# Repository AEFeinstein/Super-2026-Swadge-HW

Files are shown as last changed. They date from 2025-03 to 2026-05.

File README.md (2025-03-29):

# Super Magfest 2026 Swadge Hardware

## Welcome

This is the hardware repository for the Super Magfest 2026 Swadge.

The corresponding firmware repository for the Super Magfest 2026 Swadge [can be found here](https://github.com/AEFeinstein/Super-2024-Swadge-FW).

If you have any questions, feel free to create a Github ticket or email us at circuitboards@magfest.org.

## Render

Coming eventually!

## Schematic

Coming eventually!

## Directories

### `art`

This directory has the SVGs used to generate the KiCad files. The SVGs are drawn in [Inkscape](https://inkscape.org/).

### `Swadge-Parts`

This directory is a git submodule which has all the parts, footprints, and 3D models used in the KiCad project.

### `Swadge-HW`

This directory has the KiCad project for the main Swadge PCB.

### `Swadge-HW/3d Print`

This directory has the 3D print files for the 2026 Swadge.

### `Swadge-HW/Manufacturing Information`

This directory has information about manufacturing the Swdage PCB.

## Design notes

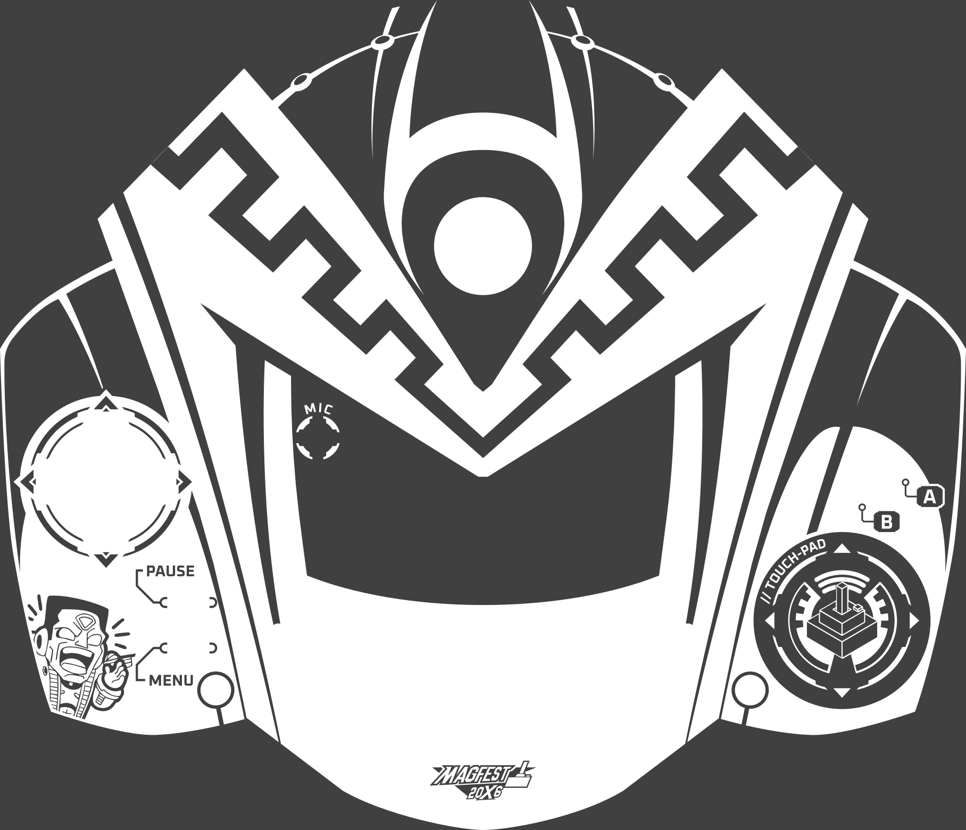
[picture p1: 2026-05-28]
art/SwadgeDesign-13-Export-01.png

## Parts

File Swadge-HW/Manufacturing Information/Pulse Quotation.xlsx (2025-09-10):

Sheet: PCB Specification
Your PCB Specification |  | Your PCB Specification
PCB Quantity | 1800pcs | PCB Quantity | 700pcs
Layer | 2layer | Layer | 2layer
PCB Thickness | 1.6mm | PCB Thickness | 1.6mm
Dimensions | 153*132mm | Dimensions | 153*132mm
Castellated Hole | No | Castellated Hole | No
PCB Color | Black | PCB Color | Blue
Surface Finish | HASL Lead Free | Surface Finish | HASL Lead Free
Copper Weight | 1oz | Copper Weight | 1oz
Text Color | White | Text Color | White
Different Design | 1 | Different Design | 1
Please find more PCB information on our on-line PCB ordering Page
https://www.elecrow.com/pcb-manufacturing.html

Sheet: BOM - BLUE
Swadge 2026 - BLUE
# | Reference | Qty | Value | Package | Manufacturer Part number | Description | SMD | THT | Original | Elecrow PN | Note
1 | R6,R18,R27,R28,R35 | 5 | 5.1kÎ© | R_0603_1608Metric | C23186 | Resistor US symbol |  |  | Y | C23186
2 | C1,C4,C5,C6,C7,C11,C15,C17,C19 | 9 | 1Î¼F | C_0603_1608Metric | C15849 | Unpolarized capacitor |  |  | Y | C15849
3 | U2 | 1 | RB017A1505A | NULL | ~ | 240x280 color TFT with rounded corners |  |  | N | ~ | Display
4 | U1 | 1 | ESP32-S2-MINI-2 | ESP32-S2-MINI-2 | C3013908 |  |  |  |  | C3013908 | Use module w. 4MB Flash, 2MB PSRAM (N4R2)
5 | U6 | 1 | LSM6DSL | LGA-14_3x2.5mm_P0.5mm_LayoutBorder3x4y | C967633 |  |  |  |  | C967633
6 | RV1 | 1 | R_Potentiometer_US_SMD | RK10J11R001Y | C3020613 | ±30% 10k? SMD-5P,14x2.5mm Potentiometers, Variable Resistors ROHS |  |  |  | C3020613
7 | U9 | 1 | INGHAi_GSPK2307P-8R1W | INGHAi GSPK2308P-8R0.5W | C530531 |  |  |  | Y | C530531
8 | MK1 | 1 | Microphone | INGHAi_MIC_GMI4013S-2C58DB | C529869 | Microphone |  |  | N | C529869
9 | BT1,BT2,BT3 | 3 | Battery | 2460 | ~ | BATT HOLDER AA 1 CELL PC PIN |  |  | Y | ~ | Use through-hole AA Battery Holder in Style of Keystone 2460. Two fins hold batteries, not four fins.
10 | U5 | 1 | RB017A1505A_Connector | HCTL HC-FPC-03-10-15RLTAG-TUCKED | C3012328 |  |  |  | Y | C3012328
11 | L1 | 1 | 33uH_500mA | L_1210_3225Metric | C90317 | Inductor |  |  | Y | C90317
12 | D11 | 1 | SP0503BAHT | SOT-143 | C2682275 | TVS Diode Array, 5.5V Standoff, 3 Channels, SOT-143 package |  |  | Y | C2682275
13 | J1 | 1 | Conn_02x03_Odd_Even | PinHeader_2x03_P2.54mm_Vertical | C92272 | Generic connector, double row, 02x03 |  |  | Y | C92272
14 | SW7,SW8 | 2 | B3FS-4002P | B3FS4002P | C5377634 | Black Cap Tactile Switch, SPST-NO 50 mA @ 24 V dc 0.4mm |  |  | Y | C5377634 | Use standard 12mmx12mm SMT box tactile buttons with flat top. Similar to TL3300DF160Q.
15 | D1,D2,D3,D4,D5,D6 | 6 | SK6812-SIDE-A | SK6812_SIDE_2 | C2890037 |  |  |  | Y | C2890037
16 | P1 | 1 | USB_C_Plug_USB2.0 | USB_C_Receptacle_HRO_TYPE-C-31-M-12 | C2765186 | USB 2.0-only Type-C Plug connector |  |  | Y | C2765186 | https://www.usb.org/sites/default/files/documents/usb_type-c.zip
17 | L3 | 1 | 2.2uH | L_1008_2520Metric | C216158 | Inductor |  |  | Y | C216158
18 | J2 | 1 | PJ-307C | PJ-307C | C16684 |  |  |  | N | C16684
19 | U8 | 1 | FM8002A | SOP-8_3.9x4.9mm_P1.27mm | C94625 | Mono Audio Amplifier |  |  | N | C94625
20 | D10,D12 | 2 | D | D_SMA | C22452 | Diode |  |  | Y | C22452
21 | U3 | 1 | M3410 | SOT-23-5 | C42420805 | M3410LB-N |  |  | Y | C42420805 | May be FP6396, M3406, LP3220S, etc...
22 | Q1 | 1 | Q_PMOS_GSD | SOT-23 | C2763847 | P-MOSFET transistor, gate/source/drain |  |  | Y | C2763847
23 | SW1,SW2,SW3,SW4,SW5,SW6 | 6 | YTS-D003-1A | YTS-D003-1A | C2910918 |  |  |  | Y | C2910918 | Use low operating force (100gf) SMT box tactile buttons
24 | U7 | 1 | GENERIC_LDO_GOI | SOT-23 | C347374 |  |  |  | Y | C347374
25 | SW9 | 1 | SW_SPDT_1825232-1 | 1825232-1 | C393937 | Slide Switch SPDT Through Hole, Right Angle |  |  | Y | C393937 | Use SPDT slide switch. Similar to 1825232-1
26 | C2,C12,C20,C22 | 4 | 22uF | C_0603_1608Metric | C159801 | Unpolarized capacitor |  |  | Y | C159801
27 | C18 | 1 | 0.39uF | C_0603_1608Metric | C376833 | Unpolarized capacitor |  |  | Y | C376833
28 | C14 | 1 | 1uF | C_0603_1608Metric | C15849 | Unpolarized capacitor |  |  | Y | C15849
29 | C9 | 1 | 4.7nF | C_0603_1608Metric | C53987 | Unpolarized capacitor |  |  | Y | C53987
30 | C21 | 1 | 2.2uF | C_0603_1608Metric | C6119848 | Unpolarized capacitor |  |  | Y | C6119848
31 | C3,C10,C13,C16,C23,C25 | 6 | 0.1uF | C_0603_1608Metric | C282519 | Unpolarized capacitor |  |  | Y | C282519
32 | R21,R25 | 2 | 43k | R_0603_1608Metric | C23172 | Resistor US symbol |  |  | Y | C23172
33 | R3 | 1 | 12k | R_0603_1608Metric | C22790 | Resistor US symbol |  |  | Y | C22790
34 | R2,R4,R8,R13,R14 | 5 | 33k | R_0603_1608Metric | C23140 | Resistor US symbol |  |  | Y | C23140
35 | R20,R23,R29,R30,R31,R32,R33,R34 | 8 | 22 | R_0603_1608Metric | C25092 | Resistor US symbol |  |  | Y | C25092 | BLUE SOLDERMASK VARIANT
36 | R19 | 1 | 120 | R_0603_1608Metric | C313655 | Resistor US symbol |  |  | Y | C313655
37 | R10,R11,R12,R15,R16,R17 | 6 | 50 | R_0603_1608Metric | C2907048 | Resistor US symbol |  |  | Y | C2907048
38 | R5,R9 | 2 | 20k | R_0603_1608Metric | C2907011 | Resistor US symbol |  |  | Y | C2907011
39 | R1,R7,R22,R24,R26 | 5 | 10k | R_0603_1608Metric | C25804 | Resistor US symbol |  |  | Y | C25804
40 | U11 | 1 | CH32V003F4U6 | QFN-20-1EP_3x3mm_P0.4mm_EP1.65x1.65mm | C5299908 |  |  |  | N | C5299908
42 | D13,D14,D15,D16,D17,D18,D19,D20,D21,D22,D23,D24,D25,D26,D27,D28,D29,D30,D31,D32,D33,D34,D35,D36,D37,D38,D39,D40,D41,D42,D43,D44,D45,D46,D47,D48,D49,D50,D51,D52,D53,D54,D55,D56,D57,D58,D59,D60,D61,D62,D63,D64,D65,D66,D67,D68,D69,D70,D71,D72,D73,D74,D75,D76,D77,D78,D79,D80,D81,D82,D83,D84 | 72 | A-SP192GB1D-A02-4T | LED 0603 | C5355458 | 20mA 1420mcd Diode Ice Blue |  |  | N | C5355458 | BLUE SOLDERMASK VARIANT

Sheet: BOM - BLACK
Swadge 2026 - BLUE
# | Reference | Qty | Value | Package | Manufacturer Part number | Description | SMD | THT | Original | Elecrow PN | Note
1 | R6,R18,R27,R28,R35 | 5 | 5.1kÎ© | R_0603_1608Metric | C23186 | Resistor US symbol |  |  | Y | C23186
2 | C1,C4,C5,C6,C7,C11,C15,C17,C19 | 9 | 1Î¼F | C_0603_1608Metric | C15849 | Unpolarized capacitor |  |  | Y | C15849
3 | U2 | 1 | RB017A1505A | NULL | ~ | 240x280 color TFT with rounded corners |  |  | N | ~ | Display
4 | U1 | 1 | ESP32-S2-MINI-2 | ESP32-S2-MINI-2 | C3013908 |  |  |  |  | C3013908 | Use module w. 4MB Flash, 2MB PSRAM (N4R2)
5 | U6 | 1 | LSM6DSL | LGA-14_3x2.5mm_P0.5mm_LayoutBorder3x4y | C967633 |  |  |  |  | C967633
6 | RV1 | 1 | R_Potentiometer_US_SMD | RK10J11R001Y | C3020613 | ±30% 10k? SMD-5P,14x2.5mm Potentiometers, Variable Resistors ROHS |  |  |  | C3020613
7 | U9 | 1 | INGHAi_GSPK2307P-8R1W | INGHAi GSPK2308P-8R0.5W | C530531 |  |  |  | Y | C530531
8 | MK1 | 1 | Microphone | INGHAi_MIC_GMI4013S-2C58DB | C529869 | Microphone |  |  | N | C529869
9 | BT1,BT2,BT3 | 3 | Battery | 2460 | ~ | BATT HOLDER AA 1 CELL PC PIN |  |  | Y | ~ | Use through-hole AA Battery Holder in Style of Keystone 2460. Two fins hold batteries, not four fins.
10 | U5 | 1 | RB017A1505A_Connector | HCTL HC-FPC-03-10-15RLTAG-TUCKED | C3012328 |  |  |  | Y | C3012328
11 | L1 | 1 | 33uH_500mA | L_1210_3225Metric | C90317 | Inductor |  |  | Y | C90317
12 | D11 | 1 | SP0503BAHT | SOT-143 | C2682275 | TVS Diode Array, 5.5V Standoff, 3 Channels, SOT-143 package |  |  | Y | C2682275
13 | J1 | 1 | Conn_02x03_Odd_Even | PinHeader_2x03_P2.54mm_Vertical | C92272 | Generic connector, double row, 02x03 |  |  | Y | C92272
14 | SW7,SW8 | 2 | B3FS-4002P | B3FS4002P | C5377634 | Black Cap Tactile Switch, SPST-NO 50 mA @ 24 V dc 0.4mm |  |  | Y | C5377634 | Use standard 12mmx12mm SMT box tactile buttons with flat top. Similar to TL3300DF160Q.
15 | D1,D2,D3,D4,D5,D6 | 6 | SK6812-SIDE-A | SK6812_SIDE_2 | C2890037 |  |  |  | Y | C2890037
16 | P1 | 1 | USB_C_Plug_USB2.0 | USB_C_Receptacle_HRO_TYPE-C-31-M-12 | C2765186 | USB 2.0-only Type-C Plug connector |  |  | Y | C2765186 | https://www.usb.org/sites/default/files/documents/usb_type-c.zip
17 | L3 | 1 | 2.2uH | L_1008_2520Metric | C216158 | Inductor |  |  | Y | C216158
18 | J2 | 1 | PJ-307C | PJ-307C | C16684 |  |  |  | N | C16684
19 | U8 | 1 | FM8002A | SOP-8_3.9x4.9mm_P1.27mm | C94625 | Mono Audio Amplifier |  |  | N | C94625
20 | D10,D12 | 2 | D | D_SMA | C22452 | Diode |  |  | Y | C22452
21 | U3 | 1 | M3410 | SOT-23-5 | C42420805 | M3410LB-N |  |  | Y | C42420805 | May be FP6396, M3406, LP3220S, etc...
22 | Q1 | 1 | Q_PMOS_GSD | SOT-23 | C2763847 | P-MOSFET transistor, gate/source/drain |  |  | Y | C2763847
23 | SW1,SW2,SW3,SW4,SW5,SW6 | 6 | YTS-D003-1A | YTS-D003-1A | C2910918 |  |  |  | Y | C2910918 | Use low operating force (100gf) SMT box tactile buttons
24 | U7 | 1 | GENERIC_LDO_GOI | SOT-23 | C347374 |  |  |  | Y | C347374
25 | SW9 | 1 | SW_SPDT_1825232-1 | 1825232-1 | C393937 | Slide Switch SPDT Through Hole, Right Angle |  |  | Y | C393937 | Use SPDT slide switch. Similar to 1825232-1
26 | C2,C12,C20,C22 | 4 | 22uF | C_0603_1608Metric | C159801 | Unpolarized capacitor |  |  | Y | C159801
27 | C18 | 1 | 0.39uF | C_0603_1608Metric | C376833 | Unpolarized capacitor |  |  | Y | C376833
28 | C14 | 1 | 1uF | C_0603_1608Metric | C15849 | Unpolarized capacitor |  |  | Y | C15849
29 | C9 | 1 | 4.7nF | C_0603_1608Metric | C53987 | Unpolarized capacitor |  |  | Y | C53987
30 | C21 | 1 | 2.2uF | C_0603_1608Metric | C6119848 | Unpolarized capacitor |  |  | Y | C6119848
31 | C3,C10,C13,C16,C23,C25 | 6 | 0.1uF | C_0603_1608Metric | C282519 | Unpolarized capacitor |  |  | Y | C282519
32 | R21,R25 | 2 | 43k | R_0603_1608Metric | C23172 | Resistor US symbol |  |  | Y | C23172
33 | R3 | 1 | 12k | R_0603_1608Metric | C22790 | Resistor US symbol |  |  | Y | C22790
34 | R2,R4,R8,R13,R14 | 5 | 33k | R_0603_1608Metric | C23140 | Resistor US symbol |  |  | Y | C23140
35 | R20,R23,R29,R30,R31,R32,R33,R34 | 8 | 47 | R_0603_1608Metric | C2907174 | Resistor US symbol |  |  | Y | C2907174 | BLACK SOLDERMASK VARIANT
36 | R19 | 1 | 120 | R_0603_1608Metric | C313655 | Resistor US symbol |  |  | Y | C313655
37 | R10,R11,R12,R15,R16,R17 | 6 | 50 | R_0603_1608Metric | C2907048 | Resistor US symbol |  |  | Y | C2907048
38 | R5,R9 | 2 | 20k | R_0603_1608Metric | C2907011 | Resistor US symbol |  |  | Y | C2907011
39 | R1,R7,R22,R24,R26 | 5 | 10k | R_0603_1608Metric | C25804 | Resistor US symbol |  |  | Y | C25804
40 | U11 | 1 | CH32V003F4U6 | QFN-20-1EP_3x3mm_P0.4mm_EP1.65x1.65mm | C5299908 |  |  |  | N | C5299908
42 | D13,D14,D15,D16,D17,D18,D19,D20,D21,D22,D23,D24,D25,D26,D27,D28,D29,D30,D31,D32,D33,D34,D35,D36,D37,D38,D39,D40,D41,D42,D43,D44,D45,D46,D47,D48,D49,D50,D51,D52,D53,D54,D55,D56,D57,D58,D59,D60,D61,D62,D63,D64,D65,D66,D67,D68,D69,D70,D71,D72,D73,D74,D75,D76,D77,D78,D79,D80,D81,D82,D83,D84 | 72 | XL-1608SURC-06FJ | LED 0603 | C7371900 | 20mA Water Clear 600mcd op View Mount 618nm~630nm Red |  |  | N | C7371900 | BLACK SOLDERMASK VARIANT

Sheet: Position File
designator | footprint | pos_x | pos_y | Layer | rotation
BT1 | 2460 | 118.6449 | -96.1958 | bottom | 90.00
BT2 | 2460 | 151.1449 | -49.7873 | bottom | 0
BT3 | 2460 | 183.6449 | -96.1958 | bottom | -90
C1 | C_0603_1608Metric | 193.7017 | -45.7603 | bottom | 45
C2 | C_0603_1608Metric | 203.8166 | -70.9114 | bottom | -135
C3 | C_0603_1608Metric | 201.7659 | -68.8608 | bottom | -135
C6 | C_0603_1608Metric | 203.4592 | -86.415 | bottom | 90
C7 | C_0603_1608Metric | 209.5592 | -90.285 | bottom | 0
C9 | C_0603_1608Metric | 138.0199 | -92.3922 | bottom | 180
C10 | C_0603_1608Metric | 164.0417 | -87.34 | bottom | 180
C11 | C_0603_1608Metric | 156.2725 | -131.82 | bottom | 180
C12 | C_0603_1608Metric | 160.9917 | -87.315 | bottom | 0
C13 | C_0603_1608Metric | 159.2042 | -85.74 | bottom | 180
C14 | C_0603_1608Metric | 140.3917 | -72.1525 | bottom | -90
C15 | C_0603_1608Metric | 131.2417 | -73.215 | bottom | 90
C16 | C_0603_1608Metric | 163.4751 | -125.8042 | bottom | -90
C18 | C_0603_1608Metric | 136.5349 | -65.3815 | bottom | 90
C19 | C_0603_1608Metric | 158.3749 | -124.6865 | bottom | -90
C20 | C_0603_1608Metric | 135.8199 | -88.5547 | bottom | 90
C21 | C_0603_1608Metric | 157.6574 | -82.69 | bottom | 180
C22 | C_0603_1608Metric | 150.9749 | -126.499 | bottom | 0
C23 | C_0603_1608Metric | 156.7749 | -124.6865 | bottom | -90
C25 | C_0603_1608Metric | 155.1749 | -124.6865 | bottom | -90
D10 | D_SMA | 152.4749 | -130.899 | bottom | -90
D11 | SOT-143 | 206.6671 | -80.9211 | bottom | 45
D12 | D_SMA | 209.0049 | -72.6811 | bottom | -120
J2 | PJ-307C | 125.566 | -31.2422 | bottom | -155
L1 | L_1210_3225Metric | 148.9949 | -129.659 | bottom | 90
L3 | L_1008_2520Metric | 206.2199 | -85.759 | bottom | 0
P1 | USB_C_Receptacle_HRO_TYPE-C-31-M-12 | 222.4127 | -75.1863 | bottom | -45
Q1 | SOT-23 | 156.0749 | -129.149 | bottom | 180
R1 | R_0603_1608Metric | 191.5362 | -47.9259 | bottom | 45
R2 | R_0603_1608Metric | 138.8449 | -88.5172 | bottom | 90
R3 | R_0603_1608Metric | 138.0324 | -90.8172 | bottom | 180
R5 | R_0603_1608Metric | 137.9042 | -69.765 | bottom | 0
R6 | R_0603_1608Metric | 187.788 | -51.574 | bottom | 45
R7 | R_0603_1608Metric | 158.67 | -129.1675 | bottom | 90
R8 | R_0603_1608Metric | 159.9667 | -83.44 | bottom | 90
R9 | R_0603_1608Metric | 134.1324 | -66.1172 | bottom | 180
R10 | R_0603_1608Metric | 215.0274 | -104.959 | bottom | 0
R11 | R_0603_1608Metric | 205.6649 | -104.989 | bottom | 180
R12 | R_0603_1608Metric | 194.1449 | -124.8172 | bottom | 0
R13 | R_0603_1608Metric | 204.9598 | -77.3582 | bottom | -45
R14 | R_0603_1608Metric | 203.1598 | -79.2582 | bottom | -45
R15 | R_0603_1608Metric | 205.2449 | -123.0295 | bottom | -90
R16 | R_0603_1608Metric | 194.6049 | -120.559 | bottom | -90
R17 | R_0603_1608Metric | 208.0449 | -118.7172 | bottom | -90
R18 | R_0603_1608Metric | 166.2542 | -82.44 | bottom | 180
R19 | R_0603_1608Metric | 141.9917 | -72.1525 | bottom | -90
R20 | R_0603_1608Metric | 154.7649 | -96.7515 | bottom | -90
R21 | R_0603_1608Metric | 209.5592 | -88.715 | bottom | 180
R22 | R_0603_1608Metric | 210.3092 | -86.3275 | bottom | 90
R23 | R_0603_1608Metric | 148.4449 | -100.9297 | bottom | -90
R24 | R_0603_1608Metric | 205.8592 | -91.915 | bottom | 180
R25 | R_0603_1608Metric | 203.5592 | -89.515 | bottom | 90
R26 | R_0603_1608Metric | 150.9749 | -124.899 | bottom | 0
R29 | R_0603_1608Metric | 155.9049 | -101.049 | bottom | 180
R31 | R_0603_1608Metric | 146.8649 | -112.1585 | bottom | -90
R33 | R_0603_1608Metric | 150.7549 | -112.499 | bottom | -90
R34 | R_0603_1608Metric | 156.5949 | -112.139 | bottom | -90
R35 | R_0603_1608Metric | 152.8874 | -91.419 | bottom | 0
RV1 | RK10J11R001Y | 85.7449 | -73.4172 | bottom | -141
SW9 | 1825232-1 | 213.3291 | -68.0832 | bottom | -30
U1 | ESP32-S2-MINI-1 | 195.9449 | -59.1172 | bottom | 135
U3 | SOT-23-5 | 206.2092 | -89.115 | bottom | -90
U6 | LGA-14_3x2.5mm_P0.5mm_LayoutBorder3x4y | 162.5167 | -85.015 | bottom | 180
U7 | SOT-23 | 160.9749 | -124.449 | bottom | 0
U8 | SOP-8_3.9x4.9mm_P1.27mm | 135.6917 | -73.365 | bottom | 180
U10 | BGA-4-.83x.83 | 160.1917 | -81.24 | bottom | 0
C4 | C_0603_1608Metric | 175.5449 | -41.9172 | top | 50
C5 | C_0603_1608Metric | 172.1449 | -91.359 | top | 180
C17 | C_0603_1608Metric | 102.3945 | -106.5957 | top | -160
D1 | SK6812_SIDE_2 | 177.2553 | -44.6795 | top | 50
D2 | SK6812_SIDE_2 | 197.0221 | -105.1283 | top | -107
D3 | SK6812_SIDE_2 | 171.4191 | -87.3315 | top | -148
D4 | SK6812_SIDE_2 | 130.2124 | -86.912 | top | 148
D5 | SK6812_SIDE_2 | 105.2533 | -105.0087 | top | 107
D6 | SK6812_SIDE_2 | 125.1704 | -44.7883 | top | -50
D13 | LED_0603_1608Metric | 127.9449 | -95.3172 | top | 45
D14 | LED_0603_1608Metric | 127.9449 | -98.3172 | top | 45
D15 | LED_0603_1608Metric | 127.9449 | -101.3172 | top | 45
D16 | LED_0603_1608Metric | 127.9449 | -104.3172 | top | 45
D17 | LED_0603_1608Metric | 127.9449 | -107.3172 | top | 45
D18 | LED_0603_1608Metric | 127.9449 | -110.3172 | top | 45
D19 | LED_0603_1608Metric | 159.707 | -107.3287 | top | 45
D20 | LED_0603_1608Metric | 159.707 | -110.3287 | top | 45
D21 | LED_0603_1608Metric | 130.9449 | -95.3172 | top | 45
D22 | LED_0603_1608Metric | 130.9449 | -98.3172 | top | 45
D23 | LED_0603_1608Metric | 130.9449 | -101.3172 | top | 45
D24 | LED_0603_1608Metric | 130.9449 | -104.3172 | top | 45
D25 | LED_0603_1608Metric | 130.9449 | -107.3172 | top | 45
D26 | LED_0603_1608Metric | 130.9449 | -110.3172 | top | 45
D27 | LED_0603_1608Metric | 162.707 | -107.3287 | top | 45
D28 | LED_0603_1608Metric | 162.707 | -110.3287 | top | 45
D29 | LED_0603_1608Metric | 133.9449 | -95.3172 | top | 45
D30 | LED_0603_1608Metric | 133.9449 | -98.5172 | top | 45
D31 | LED_0603_1608Metric | 133.9449 | -101.3172 | top | 45
D32 | LED_0603_1608Metric | 133.9449 | -104.3172 | top | 45
D33 | LED_0603_1608Metric | 133.9449 | -107.3172 | top | 45
D34 | LED_0603_1608Metric | 133.9449 | -110.3172 | top | 45
D35 | LED_0603_1608Metric | 165.707 | -107.3287 | top | 45
D36 | LED_0603_1608Metric | 165.707 | -110.3287 | top | 45
D37 | LED_0603_1608Metric | 136.9449 | -95.3172 | top | 45
D38 | LED_0603_1608Metric | 136.9449 | -98.5172 | top | 45
D39 | LED_0603_1608Metric | 136.9449 | -101.3172 | top | 45
D40 | LED_0603_1608Metric | 136.9449 | -104.3172 | top | 45
D41 | LED_0603_1608Metric | 136.9449 | -107.3172 | top | 45
D42 | LED_0603_1608Metric | 136.9449 | -110.3172 | top | 45
D43 | LED_0603_1608Metric | 168.707 | -107.3287 | top | 45
D44 | LED_0603_1608Metric | 168.707 | -110.3287 | top | 45
D45 | LED_0603_1608Metric | 139.9449 | -95.3172 | top | 45
D46 | LED_0603_1608Metric | 139.9449 | -98.3172 | top | 45
D47 | LED_0603_1608Metric | 139.9449 | -101.3172 | top | 45
D48 | LED_0603_1608Metric | 139.9449 | -104.3172 | top | 45
D49 | LED_0603_1608Metric | 139.9449 | -107.3172 | top | 45
D50 | LED_0603_1608Metric | 139.9449 | -110.3172 | top | 45
D51 | LED_0603_1608Metric | 171.707 | -107.3287 | top | 45
D52 | LED_0603_1608Metric | 171.707 | -110.3287 | top | 45
D53 | LED_0603_1608Metric | 142.9449 | -95.3172 | top | 45
D54 | LED_0603_1608Metric | 142.9449 | -98.3172 | top | 45
D55 | LED_0603_1608Metric | 142.9449 | -101.3172 | top | 45
D56 | LED_0603_1608Metric | 142.9449 | -104.3172 | top | 45
D57 | LED_0603_1608Metric | 142.9449 | -107.3172 | top | 45
D58 | LED_0603_1608Metric | 142.9449 | -110.3172 | top | 45
D59 | LED_0603_1608Metric | 174.707 | -107.3287 | top | 45
D60 | LED_0603_1608Metric | 174.707 | -110.3287 | top | 45
D61 | LED_0603_1608Metric | 159.707 | -95.3287 | top | 45
D62 | LED_0603_1608Metric | 168.707 | -95.3287 | top | 45
D63 | LED_0603_1608Metric | 159.707 | -98.3287 | top | 45
D64 | LED_0603_1608Metric | 168.707 | -98.3287 | top | 45
D65 | LED_0603_1608Metric | 159.707 | -101.3287 | top | 45
D66 | LED_0603_1608Metric | 168.707 | -101.3287 | top | 45
D67 | LED_0603_1608Metric | 159.707 | -104.3287 | top | 45
D68 | LED_0603_1608Metric | 168.707 | -104.3287 | top | 45
D69 | LED_0603_1608Metric | 162.707 | -95.3287 | top | 45
D70 | LED_0603_1608Metric | 171.707 | -95.3287 | top | 45
D71 | LED_0603_1608Metric | 162.707 | -98.3287 | top | 45
D72 | LED_0603_1608Metric | 171.707 | -98.3287 | top | 45
D73 | LED_0603_1608Metric | 162.707 | -101.3287 | top | 45
D74 | LED_0603_1608Metric | 171.707 | -101.3287 | top | 45
D75 | LED_0603_1608Metric | 162.707 | -104.3287 | top | 45
D76 | LED_0603_1608Metric | 171.707 | -104.3287 | top | 45
D77 | LED_0603_1608Metric | 165.707 | -95.3287 | top | 45
D78 | LED_0603_1608Metric | 174.707 | -95.3287 | top | 45
D79 | LED_0603_1608Metric | 165.707 | -98.3287 | top | 45
D80 | LED_0603_1608Metric | 174.707 | -98.3287 | top | 45
D81 | LED_0603_1608Metric | 165.707 | -101.3287 | top | 45
D82 | LED_0603_1608Metric | 174.707 | -101.3287 | top | 45
D83 | LED_0603_1608Metric | 165.707 | -104.3287 | top | 45
D84 | LED_0603_1608Metric | 174.707 | -104.3287 | top | 45
J1 | PinSocket_2x03_P2.54mm_Vertical | 175.1449 | -30.7172 | top | 90
MK1 | INGHAi_MIC_GMI4013S-2C58DB | 124.9449 | -91.559 | top | 0
R4 | R_0603_1608Metric | 174.498 | -47.1922 | top | -40
R27 | R_0603_1608Metric | 209.5598 | -81.5718 | top | 45
R28 | R_0603_1608Metric | 212.2217 | -78.8722 | top | 45
R30 | R_0603_1608Metric | 148.9449 | -105.7297 | top | 90
R32 | R_0603_1608Metric | 148.9449 | -108.9297 | top | 90
SW1 | YTS-D003-1A | 91.3449 | -92.8172 | top | 45
SW2 | YTS-D003-1A | 97.0668 | -98.5391 | top | -45
SW3 | YTS-D003-1A | 85.5784 | -98.5836 | top | 135
SW4 | YTS-D003-1A | 91.3003 | -104.3056 | top | -135
SW5 | YTS-D003-1A | 104.25 | -124.995 | top | 180
SW6 | YTS-D003-1A | 104.25 | -117.875 | top | 180
SW7 | B3FS4002P | 208.0724 | -97.5204 | top | -60
SW8 | B3FS4002P | 219.504 | -90.9204 | top | -60
U2 | NULL | -28.508 | -117.0182 | top | 0
U5 | HCTL_HC-FPC-03-10-15RLTAG-TUCKED | 151.1449 | -128.8172 | top | 0
U9 | INGHAi_GSPK2308P-8R0.5W | 151.3449 | -61.0172 | top | 0
U11 | QFN-20-1EP_3x3mm_P0.4mm_EP1.65x1.65mm | 153.3049 | -107.7872 | top | 180

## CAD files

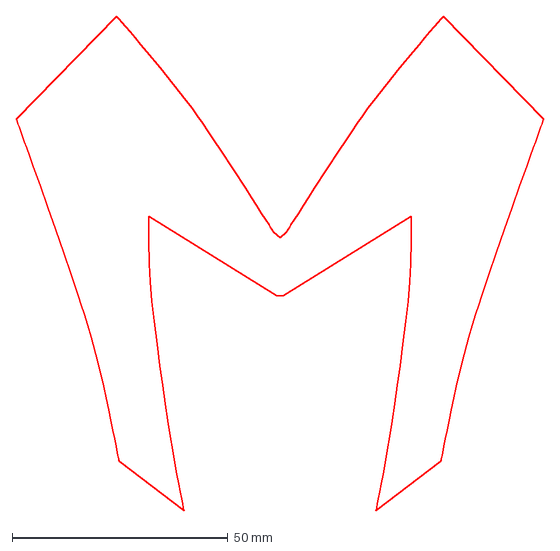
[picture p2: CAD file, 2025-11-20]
art/acylic_10102025.dxf
122.3 x 114.6 mm

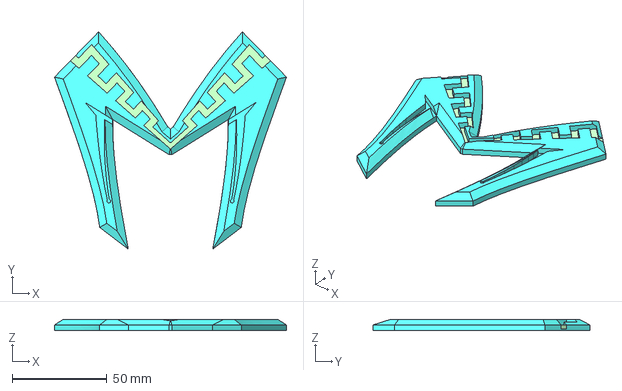
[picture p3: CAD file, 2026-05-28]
Swadge-HW/3D-Print/M-Diffuser.step
122.3 x 114.6 x 6.00 mm

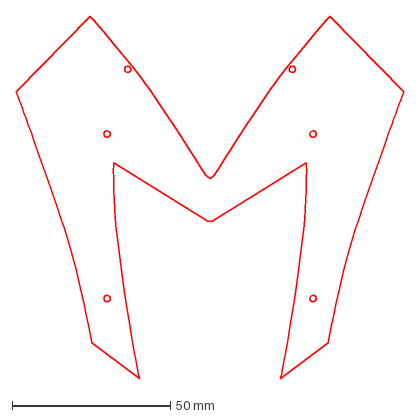
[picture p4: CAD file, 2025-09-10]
art/acrylic_992025.dxf
122.3 x 114.6 mm

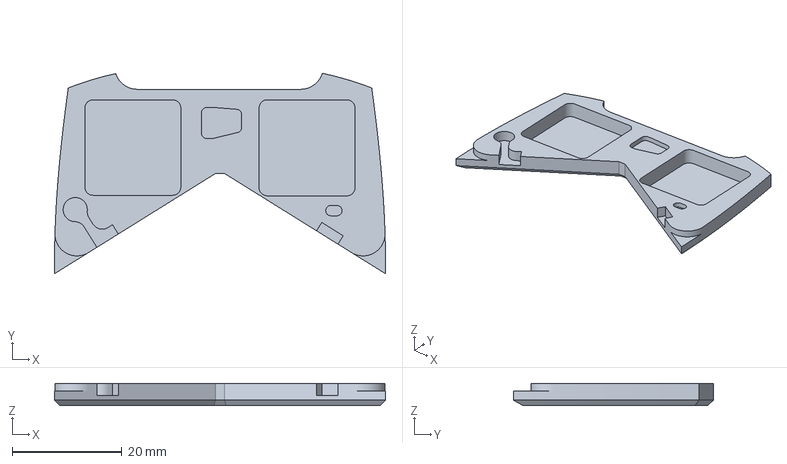
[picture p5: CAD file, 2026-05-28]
Swadge-HW/3D-Print/Open-Visor-orca.3mf
60.3 x 36.5 x 4.05 mm

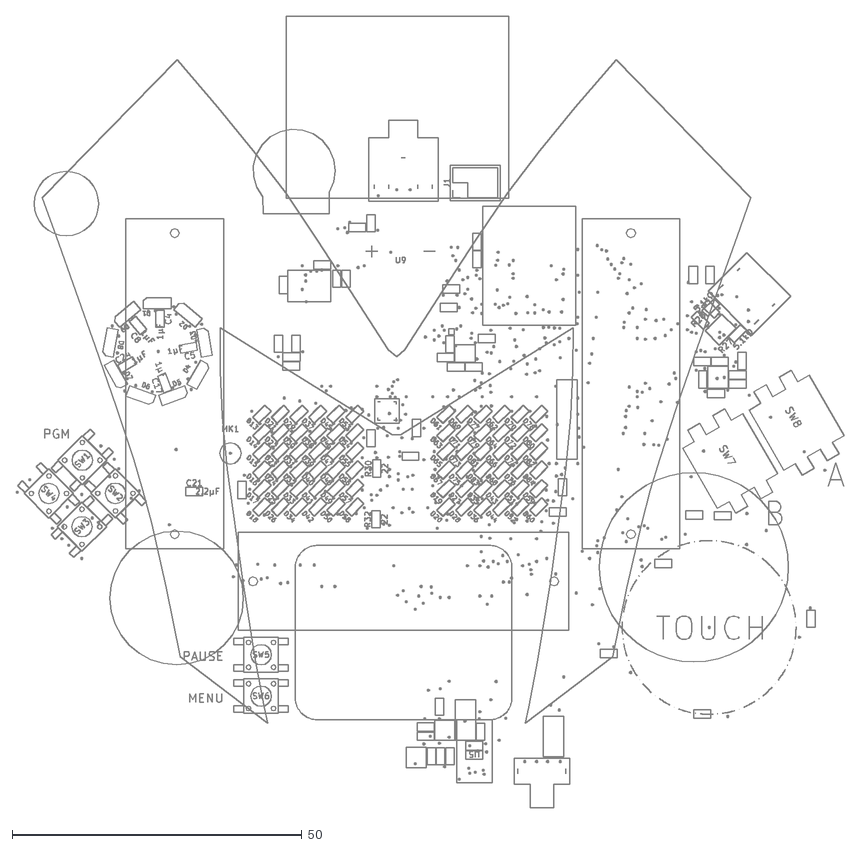
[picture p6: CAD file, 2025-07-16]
art/acrylic_7162025.dxf
142.9 x 136.6

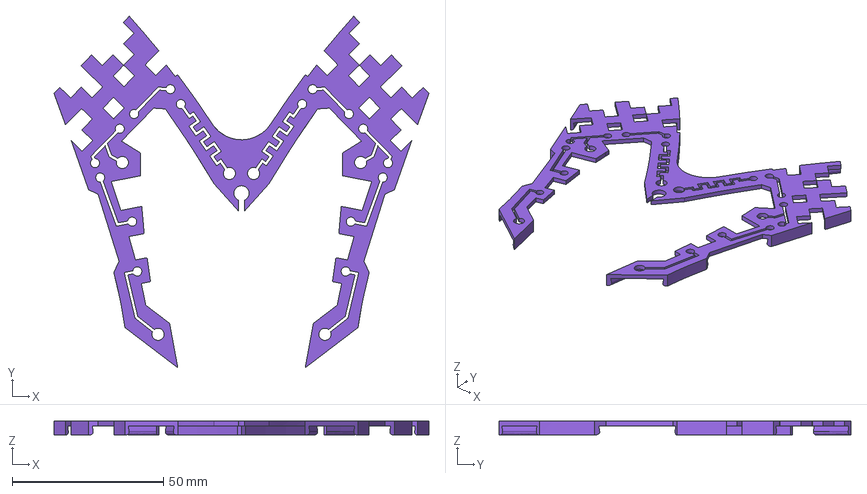
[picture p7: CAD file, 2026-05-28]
Swadge-HW/3D-Print/Corruption Crest.step
124.0 x 116.3 x 4.60 mm

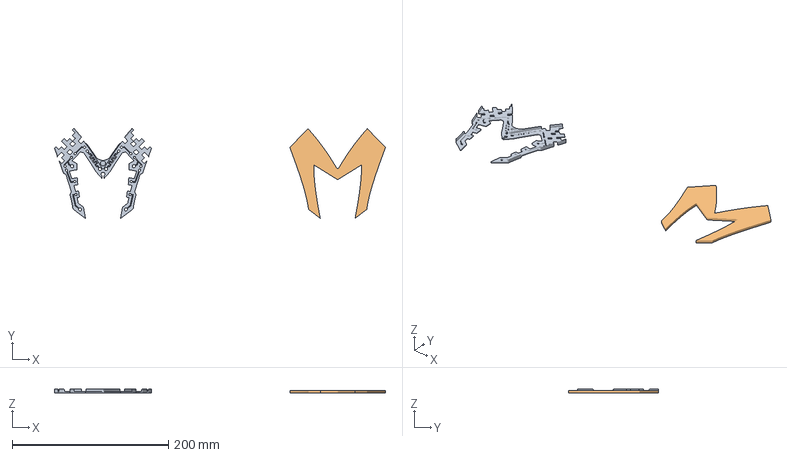
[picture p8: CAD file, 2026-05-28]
Swadge-HW/3D-Print/Corruption-Crest+Acrylic-Orca.3mf
423.2 x 115.4 x 4.60 mm
Corruption-Crest
Faux-Acrylic

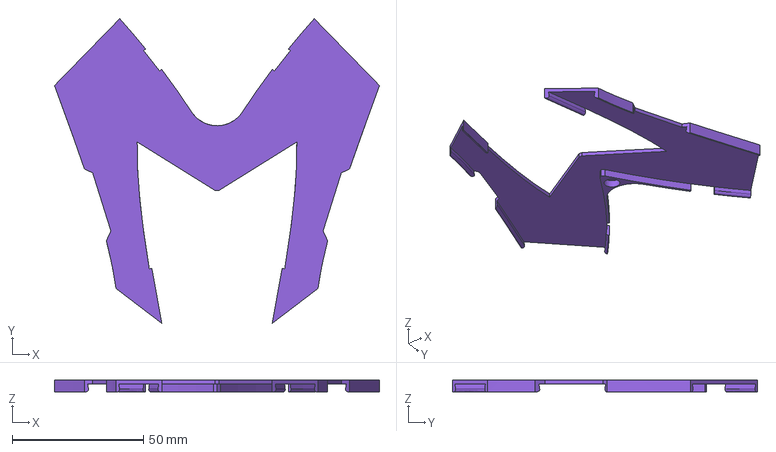
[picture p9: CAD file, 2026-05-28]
Swadge-HW/3D-Print/Crest-Diffuser-Template.step
124.0 x 116.3 x 4.60 mm

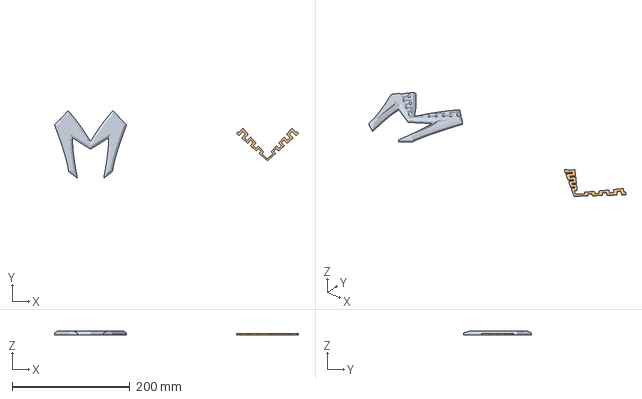
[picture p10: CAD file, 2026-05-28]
Swadge-HW/3D-Print/Fancy-M-Diffuser.3mf
413.9 x 114.6 x 6.00 mm
M-Diffuser.stl_1
M-Diffuser.stl_2

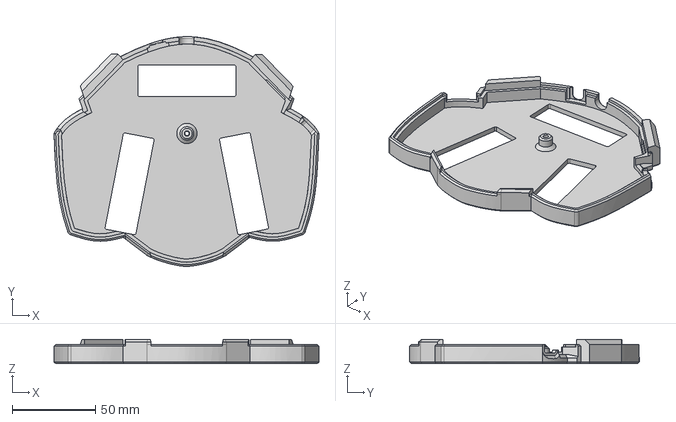
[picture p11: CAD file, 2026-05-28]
Swadge-HW/3D-Print/Wub-Tank-Proto.step
159.3 x 138.2 x 14.6 mm

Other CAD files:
Swadge-HW/3D-Print/Pulse-Visor.step
Swadge-HW/3D-Print/Open-Visor-orca-MK4.3mf

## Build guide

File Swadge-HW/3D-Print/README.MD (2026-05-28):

# Super 2026 Swadge 3D Printing Assets

Introducing the WUB TANK, the newest addition to the Swadge shell collection

## Built With

* [Fusion 360]( https://www.autodesk.com/products/fusion-360/overview?term=1-YEAR&tab=subscription) 
* [Blender](https://www.blender.org) 
* [Orcaslicer](https://github.com/OrcaSlicer/OrcaSlicer?tab=readme-ov-file)

## Getting Started

The included files are STEP type so they can be modified to your liking, and most slicer programs will readily load them. The Wub-Tank-Proto.step is the final fit check model before art assets were added. Designed to be readily printable. Recommended settings: 0 top/bottom layers for exposed (honeycomb) infill effect when printed as is.

## Recommended Materials

PLA 
PETG
TPU

## Assembly

The WUB TANK Shell requires a single M3x8 screw.

## Secret 3D Upgrade Add-ons

In addition to the shell model, there are a number of 3D-printable accessories for the Swadge this year. There are STEP files for each, and customized Orcaslicer 3MF project files are also included as reference, or ready to print for the Prusa Core ONE. 

- Pulse-Visor: SPECIFIC FILAMENT REQUIRED. The Pulse Visor was designed to be printed with Cookiecad "Black Star Stuff PLA". Clear PLA or PETG should work as well. As long as the filament isn't to opaque, the lens region of the visor should be thin enough to see the LED's but they may be obscured. Install using thin double-sided tape. Try printing this with a holographic print bed. Enjoy!

- Corruption Crest: A friction fit add-on that attaches to the standard acrylic diffuser. It was designed to be one of several Megaman style powerups. I recommend printing this in purple filament.

- Crest Diffuser Template: A version of the corruption crest with all original art removed so you can design your own. GO NUTS! Just don't cut away the tabs that hold it on.

- M-Diffuser: WARNING ADVANCED!!! Designed as a substitute for the included acrylic diffuser, since the prototype did not include one. If you want to make one, you'll need some clear/translucent filament, double sided tape, and be gentle when removing the acrylic so as not to damage the PCB surface. For best results use a clear filament and 100% concentric infill for the bottom 3mm, and a translucent color for the remainder with the top layers turned off to expose the infill with your choice of infill pattern. Print the squarewave insert seperately (in neon green or glow in the dark filament). Optional... change filament partway through to make it extra fancy.

## Contributing

Contributions are what make the open-source community such an amazing place to learn, inspire, and create. Any contributions you make are greatly appreciated!

If you have a suggestion that would make this better, please fork the repo and create a pull request. You can also simply open an issue with the tag "enhancement".
Don't forget to give the project a star! Thanks again!

1. Fork the Project
2. Create your Feature Branch (`git checkout -b feature/AmazingFeature`)
3. Commit your Changes (`git commit -m 'Add some AmazingFeature'`)
4. Push to the Branch (`git push origin feature/AmazingFeature`)
5. Open a Pull Request

## License

[MIT License](https://github.com/AEFeinstein/Super-2026-Swadge-HW/blob/main/LICENSE)

## Contact

* Emily Anthony - [@thelegendofemily](https://www.thelegendofemily.com) 
* Greg Lord - [@gplord](https://www.gplord.com/)
* Erik Jacobs - [@Eriktronic3D]

## Acknowledgments

* The Swadge team for idea generation, continuous feedback, and excellent vibes
* MAGFest volunteers and employees for their overwhelming support and willingness to help push this side project

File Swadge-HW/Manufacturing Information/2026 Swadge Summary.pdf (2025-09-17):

Subject: PCB Hardware RFQ for Magfest 2026 Swadge | September 17 2025

To: Roy@elecrow.com

Summary of Request:

Qty 2500 pcs assembled, flashed and tested with acrylic piece, two identical PCBs except solder mask color, specified below.

There is a BOM difference between the BLACK and BLUE PCBs. See included BOMs.

Please quote HASL Lead Free finish.

Please use existing inventory from the 2024 swadge order first from the 015-Magfest warehouse and deduct the cost of materials accordingly.

PCB Properties:

1. Two layer board
2. Two-side assembly
3. 1.6mm FR4
4. Qty 700 BLUE solder mask and associated BOM
5. Qty 1800 BLACK solder mask and associated BOM
6. White silkscreen on both
7. V-groove where possible, avoid sharp edges wherever possible. We want to approve tooling locations
8. 1oz Copper
9. Silkscreen should be sharp, not splotchy

Acrylic Properties:

1. One piece of acrylic per-PCB, mockup image is shown below in Assembly section
2. Matte Transparent (P422)
a. “Winter Melon White”
b. Edge should be matte, not clear
3. 3mm thick
4. No engraving

To: Roy@elecrow.com

Assembly Information:

There are 8 THT parts. These parts shall have their leads clipped close to PCB. See notes below.

Through hole leads shall not be sharp.

1. 3x AA holder -> BT1, BT2, BT3
a. Be sure that there are no cold or partial solder joints. There have been issues in the past with these joints.
2. 1x Headphone Jack -> J2
a. The jack has a lip that should overhang the pcb. Example of one that doesn’t is shown below. This should overhang correctly and sit flush.

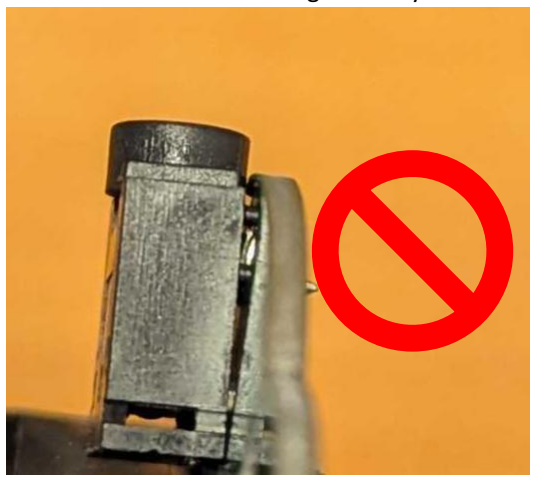
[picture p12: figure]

3. 1x Speaker -> U9
a. Speaker leads are polarized; + hole is clearly marked on both sides of the board silkscreen and must be oriented correctly.
4. 1x Switch -> SW6
a. No specific notes for this component
5. 1x 3x2 Pin Socket -> J1
a. No specific notes for this component
6. 1x Volume control knob -> RV1
a. No specific notes for this component

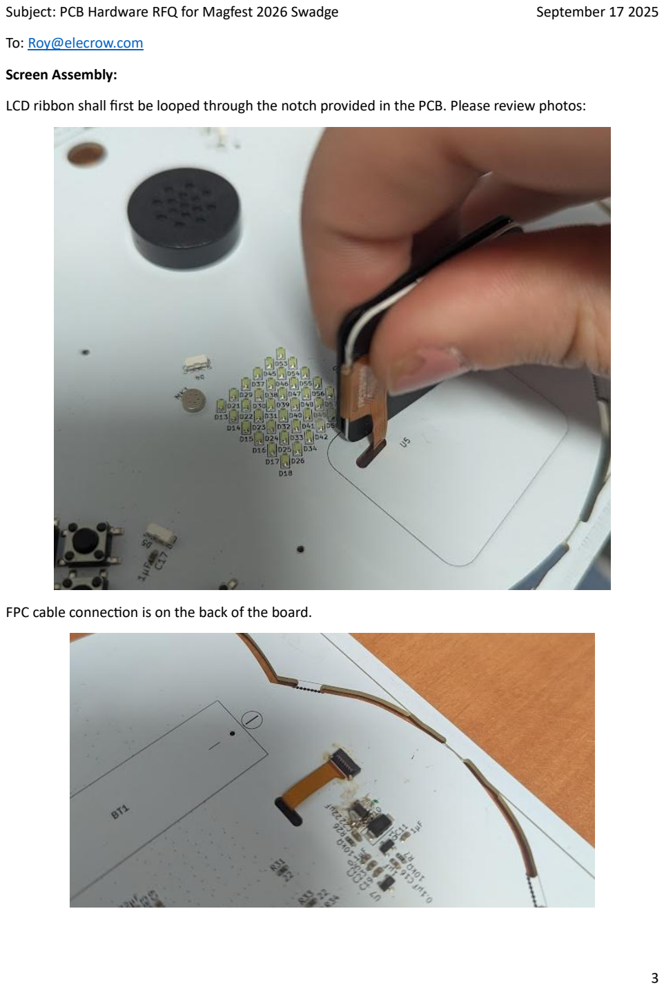
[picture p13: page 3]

To: Roy@elecrow.com

Screen Assembly:

LCD ribbon shall first be looped through the notch provided in the PCB. Please review photos:

FPC cable connection is on the back of the board.

To: Roy@elecrow.com

The ribbon cable shall have no twists to be installed – it is simply a fold through the hole to the other side of the board.

LCD shall be taped down after plugging in using double sided tape to PCB. Please use clear, thin, double-sided tape like this 0.1mm PET:

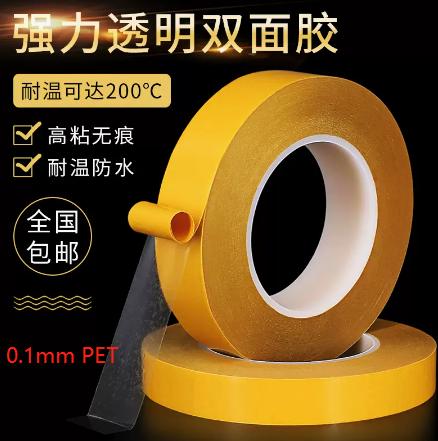
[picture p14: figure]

LCD should land approximately within the silkscreen bounds drawn and be straight.

To: Roy@elecrow.com

Acrylic Assembly:

Acrylic must have protective paper peeled off and taped to PCB using the same double-sided tape as the display. Acrylic will be approximately flush with the board edges.

Image of Acrylic, highlighted in green. LEDs are adjacent to the acrylic in the circled locations:

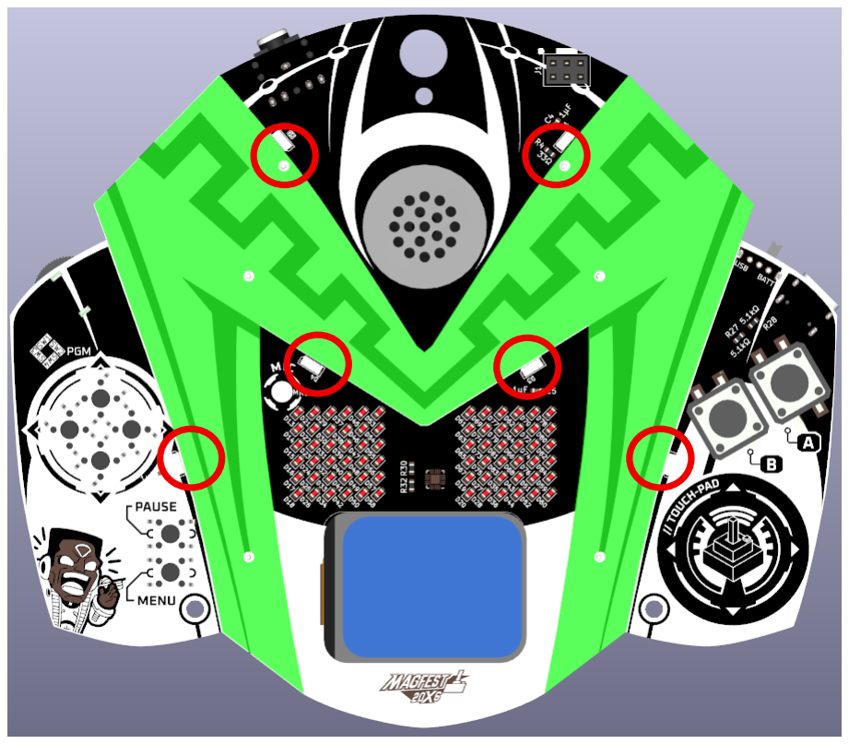
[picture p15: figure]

It is recommended to apply two pieces of tape in the following general locations underneath the acrylic, shown as rectangles in red. Do not use glue.

Tape dimensions for the acrylic shall be as follows:

- No greater than 7mm in width
- 45mm in length

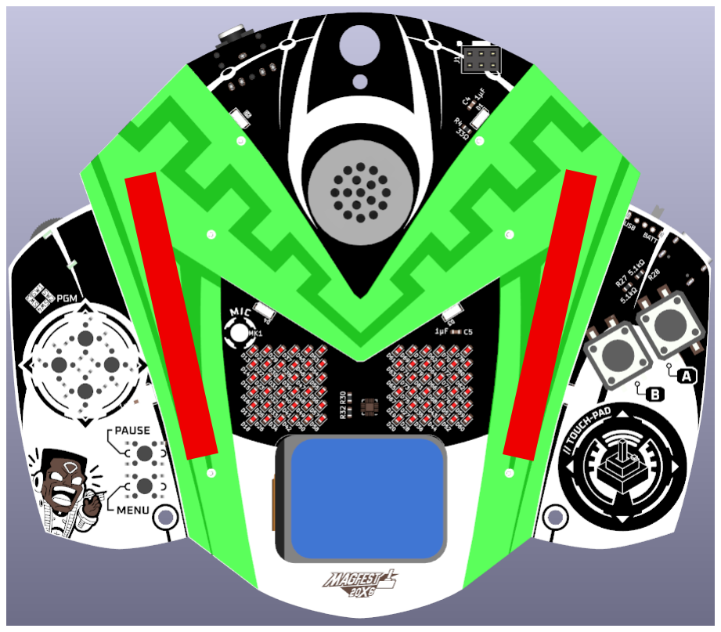
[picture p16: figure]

To: Roy@elecrow.com

Programming:

1. A Python programming script will be provided.
2. The boards connect with USB-C and do not require external programming hardware
3. The programming script can program many units in parallel
4. Each unit is programmed in ~15 seconds

Instructions will be provided.

Testing:

1. Each unit will be tested after programming.
2. Testing involves pressing all buttons and validating the display and LEDs.
3. We also have an IMU calibration step which requires the device be held on its face, then its back for 5 seconds each. Then held upright, and upside down for 5 seconds each.

Detailed instructions and video will be provided.

To: Roy@elecrow.com

Schedule:

Supplier deliveries:

August 5 2025: SZLED shipped qty 20,000 of 4020RGB LEDs to Elecrow
September 5 2025: Ronbo Electronics shipped 2,500 of RB017A1505A-CG01A LCD to Elecrow

Manufacturing Timeline:
Week 0:
September 9, 2025: RFQ Submitted by MAGFest to Elecrow
Week 1:
September 16, 2025: Quote completed and returned to MAGFest.
Upon Receipt of quote or prior: MAGFest will submit final documents to Elecrow September 19, 2025: MAGFest will pay Elecrow for samples and full order.
September 19, 2025: Elecrow will purchase components for a full 2500 order.
Week 2:
September 26, 2025: MAGFest will provide basic test firmware for boards.
Week 5:
October 14, 2025: Elecrow will send MAGFest QTY 10 PCBs as samples, via DHL ASAP. Please do not use re-shipper.
To avoid delays, any components that could not be sourced in time may be unpopulated, we have spares in the USA. Please check with us first.
Week 7:
October 31, 2025: MAGFest will provide feedback needed and will approve the final order of 2500. Week 10:
November 11, 2025: MAGFest will provide FINAL firmware to be flashed to all units OR direct Elecrow to flash test firmware only at or before this date.
Week 13:
December 2, 2025: Elecrow will ship MAGFest full 2500 order via DHL ASAP.
Please do not use reshipper.

Expect delivery in Maryland, USA on or prior to December 15 2025.

To: Roy@elecrow.com

Changelog:

Added RV1 to list of THT components Added Length and Width of acrylic tape

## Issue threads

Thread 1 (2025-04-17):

Evaluate different power options

emilyanthony4244, 2025-04-17:
Attendees are reporting that their Swadges are too heavy. This is largely due to the 3xAA batteries, 24g each, used to power the Swadge in a 1P3S configuration.

This issue will track various parallel endeavors to evaluate other power options.

Goals:

1. Capture power draw data and characterize battery usage on the Swadge
2. Determine minimum viable battery requirements from power usage
3. Design new power management circuit, if required, to accommodate a new power solution
4. Perform cost analysis on BOM and source components if required

emilyanthony4244, 2025-05-19:
Tariffs are likely going to make this a non-starter for 2026. CR123a replacements are too expensive for the end user, and 18650s are too expensive with the current political climate.

I received a quote from Battery Junction for 18650s, and received the following information:

1. Panasonic CR123 is $1.70 each; we have drafted power options with qty 3
2. 18650 shortages in the USA due to tariffs and I was sincerely discouraged from ordering them
3. Panasonic AA at $0.26 ea, and they can pack them in 3 packs for 34c each pack. This is cheaper than our current source (Kirkland at 33c ea) and I think we should consider just supplying Swadges with 6 batteries this year.

AEFeinstein, 2025-05-19:
Six batteries? Are you mad? Do you think this is a GameGear?! Three should be enough to last the weekend, or at least that's the requirement. If you're gonna make them swap, drop back down to two.

emilyanthony4244, 2025-05-19:
Switching back to two with a spare set of batteries is not something that I considered, frankly. I was more thinking if we cook the AAs with the new hardware adds I'd like to give the attendees some reprieve.

AEFeinstein, 2025-05-19:
I'd rather not cook 3xAA to begin with. We can order extras and keep them at the merch both in case of emergency. Giving out that many batteries to begin with has not great optics.

Closed 2025-05-29.

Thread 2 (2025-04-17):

RTC Evaluation

emilyanthony4244, 2025-04-17:
Devs have expressed interest in RTC (Real Time Clock).

This issue will track various parallel endeavors to evaluate RTC options.

Goals:

1. Evaluate external and internal RTC solutions
2. Demonstrate usability and evaluate value add
3. Perform cost analysis on BOM and source components if required

### Relevant ESP documentation:

https://docs.espressif.com/projects/esp-idf/en/v5.4.1/esp32s2/api-reference/system/system_time.html
https://docs.espressif.com/projects/esp-hardware-design-guidelines/en/latest/esp32s2/schematic-checklist.html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

emilyanthony4244, 2025-04-18:
Evaluating @johnnywycliffe's design:
https://github.com/johnnywycliffe/swadge-sao-rtc

First impressions, I really like the idea of an external RTC despite the cost add, as we're lacking in GPIO. My evaluation is mostly to justify the add of the IC vs the existing 40MHz RTC module that already exists on the ESP32-S2-MINI-2-N4R2.

The selected chip is a Maxim DS1307, which is pricey on LCSC (51c for 2500), but there are a couple clones that I think would be suitable. Specifically:
[C42421870](https://www.lcsc.com/product-detail/Real-Time-Clocks_TDSEMIC-DS1307-TD_C42421870.html?s_z=n_DS1307) TDSEMIC at 6c apiece
[C18723598](https://www.lcsc.com/product-detail/Real-Time-Clocks_XBLW-DS1307DTR-XBLW_C18723598.html?s_z=n_DS1307) XBLW at 7c apiece

The DS1307+ from MAXIM is only 5V supply. Depending on how we do power on the swadge this might be fine, but it is something that we need to think about. Should we boost up to 5 for this, or tap into the unregulated battery voltage upstream of the buck converter? How would this change if we switched to Lithium cells? Chew on it.

As drawn, I don't think the 3v3 from the SAO power is sufficient to power this chip and I recommend adding a boost converter to do this testing. I also recommend breaking out the SQW/OUT to the J2 testing header so we can scope it and see if the chip is functioning. I also wonder how we could creatively use this square wave generator - it can do 1Hz, 4kHz, 8kHz, and 32kHz. If you give me the whole chip, I wanna use the whole chip!

As far as i2c is concerned - the address is 0x68 which does not conflict with other i2c addresses on the bus. Please add pull-up resistors close to the IC; something like 5.1k should be sufficient.

Regarding layout, for EMI reasons I would move C3 down here:

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

Reading [this](https://ww1.microchip.com/downloads/en/DeviceDoc/Atmel-8128-Best-Practices-for-the-PCB-Layout-of-Oscillators_ApplicationNote_AVR186.pdf) application note regarding crystal isolation, the board looks fine but if we needed to shield it further I'd do something like this:

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
with 1pF on the Xin and 2pF on the Xout, plus a ground plane around the crystal.

emilyanthony4244, 2025-08-14:
Not pursuing for 2026, should reevaluate for 2027.

Closed 2025-08-14.

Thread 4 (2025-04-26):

Hardware addition - Swadgepass LED

johnnywycliffe, 2025-04-26:
## Description
A small indicator LED (or several, if single color) used to indicate the status of the swadgepass mode

- Green for new message
- Yellow for on, active
- Red for low power

## Implementation

Using the RGB LEDs is expensive power-wise. These should be singular LEDs that have larger current limiting resistors. They will be dimmer, but will draw less power.

If we run into more I/O issues, we could consider instead of using more colors would could utilize patterns like blinking fast or slow.

If we have only two LEDs (Green solid for on, slow pulse for new message and red for low power) we could use the bootstrap pins, since they won't be able to assert a signal on boot.

AEFeinstein, 2025-04-26:
RGB LEDs only draw lots of current if you let them. Adding another isn't so bad. I wonder if it'd be clearer to have a notification on the main menu for SwadgePass rather than an LED. I really hate inferring information from color or blinks.

johnnywycliffe, 2025-04-26:
I was thinking the signaling to the LEDs but yeah you're probably right

Closed 2025-05-24.

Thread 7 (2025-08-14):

MT3410LB voltage regulator obsolete

emilyanthony4244, 2025-08-14:
https://github.com/AEFeinstein/Swadge-Parts/issues/10 is tracking the Swadge-Parts update required prior to submitting RFQ to Elecrow. This problem was mitigated on the prototypes, but this is a discrepancy between requested BOM and delivered part.

New datasheet: https://www.lcsc.com/datasheet/C42420805.pdf
Old datasheet: https://www.lcsc.com/datasheet/C883494.pdf

These should be compared to verify that this new component is still the appropriate solution for the Swadge. It's "probably fine" and JLC recommended they assemble with the new component per guidance from the chip manufacturer, but I wanted to capture this in an issue so it's documented the right way.

thaeli, 2025-08-14:
Note - I had old/new parts backwards above!

So it's lower current draw. Sweet. Only decrease is Vin went from 7v to 6v but 3 fresh alkaline AA batteries are only 4.8v so we're not anywhere near that being a problem.

AEFeinstein, 2025-08-15:
The parts are so similar they didn't bother to change the name on the datasheet. That's kinda dangerous. Not for us though, I like loiwer voltages and less current draw!

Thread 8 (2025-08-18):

Microphone obsolete

emilyanthony4244, 2025-08-18:
Issue identified in the prototype build, JLC seems to have mitigated it but we'll need to get it sorted for production.

[C2835889 ](https://www.lcsc.com/product-detail/C2835889.html?s_z=n_%2520C2835889) and [C529870](https://www.lcsc.com/product-detail/C529870.html?s_z=n_C529870) marked obsolete this week. Time to find another.

AEFeinstein, 2025-08-19:
D'oh. @cnlohr got a preference?

cnlohr, 2025-08-19:
(side-note, from the last tests I had done previously 58 was a biiiit on the hot side so it's not a bad thing to go down to 56dB)

AEFeinstein, 2025-08-19:
Hot as in sensitive or Fahrenheit?

Closed 2025-09-03.

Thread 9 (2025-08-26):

Tracking rev A prototype errors and improvements

emilyanthony4244, 2025-08-26:
1. Generally, need **_thorough_** BOM review before sending to JLCPCB.
2. L1 footprint incorrect. mitigated on prototype, need to fix for next rev. was 0603 in the library, should be 1210. probably a library issue that caused it, need to check what footprint is associated with the symbol on the schematic.
3. L3 footprint incorrect. mitigated on prototype, need to fix for next rev. was 0603 in the library, should be 1008. probably a library issue that caused it, need to check what footprint is associated with the symbol on the schematic.
4. SAO connector was flipped 180 degrees. fixed (but not before shorting the frankenSwadge and killing it lmao rip)
5. Pinout on CH32v003 to LEDs incorrect, . Need to reference pinout on https://github.com/cnlohr/cnhardware/tree/master/ch32v003/ledarray-badgetest. Mitigate on prototypes by flipping the LEDs, but we really just need to redo the schematic and hardware to reflect this configuration.
6. D6 was not lighting, need to hook this up with another prototype and see if it was a 1 time problem or something worse.
7. WS2812Bs were pretty far from the acrylic. acrylic needs a rev anyway, should bump these closer or resize the plastic.
8. Battery terminal holes not cut in the acrylic, mitigated on prototype but should be fixed before reordering.

emilyanthony4244, 2025-08-27:
D6 not lighting was due to damage to that lamp. other protos look fine. not worried about this.

emilyanthony4244, 2025-09-03:
936f52f has been pushed to address 2-6. pls check my work. acrylic needs adjustment, but this will be done alongside the silkscreen additions since they're both done in inkscape.

AEFeinstein, 2025-09-04:
OK, resolved all my notes _except_ adding ground fill between the TFT traces as of 099a8e610e007ccfcd5765e31b8731020fb070e7

AEFeinstein, 2025-09-06:
Should be good now, compared to hotdog
* 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
* 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
* 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

AEFeinstein, 2025-09-09:
I regret to inform you that the touchpad part is still busted. All of the sections have `F.Mask` set (which means _don't_ mask the copper), and one also has `F.Paste` (tin the pad). Neither should be set:

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

I fixed that in [Swadge-Parts 613e5b9](https://github.com/AEFeinstein/Swadge-Parts/commit/613e5b96c1aaaec4079aa0151caf400ddd319429), but there are still a number of DRC errors. All are kind of whatever except for the first, which is new to me. Maybe the import didn't close the polygon?

```
[padstack_invalid]: Padstack is not valid (custom pad shape must resolve to a single polygon)
    Local override; error
    @(173.8700 mm, 125.2000 mm): Pad 5 [Net-(U4-Left)] of U4 on F.Cu
[clearance]: Clearance violation (netclass 'Default' clearance 0.1800 mm; actual 0.0000 mm)
    Rule: netclass 'Default'; error
    @(168.8700 mm, 108.7000 mm): Pad 1 [Net-(U4-Bottom)] of U4 on F.Cu
    @(174.0422 mm, 120.9583 mm): Polygon [<no net>] of U4 on F.Cu
[clearance]: Clearance violation (netclass 'Default' clearance 0.1800 mm; actual 0.0000 mm)
    Rule: netclass 'Default'; error
    @(168.8700 mm, 108.7000 mm): Pad 1 [Net-(U4-Bottom)] of U4 on F.Cu
    @(174.0422 mm, 120.9583 mm): Polygon [<no net>] of U4 on F.Cu
[clearance]: Clearance violation (netclass 'Default' clearance 0.1800 mm; actual 0.0000 mm)
    Rule: netclass 'Default'; error
    @(168.8700 mm, 108.7000 mm): Pad 1 [Net-(U4-Bottom)] of U4 on F.Cu
    @(174.0422 mm, 120.9583 mm): Polygon [<no net>] of U4 on F.Cu
[clearance]: Clearance violation (netclass 'Default' clearance 0.1800 mm; actual 0.0000 mm)
    Rule: netclass 'Default'; error
    @(168.8700 mm, 108.7000 mm): Pad 1 [Net-(U4-Bottom)] of U4 on F.Cu
    @(174.0422 mm, 120.9583 mm): Polygon [<no net>] of U4 on F.Cu
[clearance]: Clearance violation (netclass 'Default' clearance 0.1800 mm; actual 0.0000 mm)
    Rule: netclass 'Default'; error
    @(160.8700 mm, 134.2000 mm): Pad 4 [Net-(U4-Top_Left)] of U4 on F.Cu
    @(149.7678 mm, 127.3284 mm): Polygon [<no net>] of U4 on F.Cu
[clearance]: Clearance violation (netclass 'Default' clearance 0.1800 mm; actual 0.0000 mm)
    Rule: netclass 'Default'; error
    @(160.8700 mm, 134.2000 mm): Pad 4 [Net-(U4-Top_Left)] of U4 on F.Cu
    @(149.7678 mm, 127.3284 mm): Polygon [<no net>] of U4 on F.Cu
[clearance]: Clearance violation (netclass 'Default' clearance 0.1800 mm; actual 0.0000 mm)
    Rule: netclass 'Default'; error
    @(160.8700 mm, 134.2000 mm): Pad 4 [Net-(U4-Top_Left)] of U4 on F.Cu
    @(151.7864 mm, 126.0323 mm): Polygon [<no net>] of U4 on F.Cu
[clearance]: Clearance violation (netclass 'Default' clearance 0.1800 mm; actual 0.0000 mm)
    Rule: netclass 'Default'; error
    @(160.8700 mm, 134.2000 mm): Pad 4 [Net-(U4-Top_Left)] of U4 on F.Cu
    @(151.7864 mm, 126.0323 mm): Polygon [<no net>] of U4 on F.Cu
[clearance]: Clearance violation (netclass 'Default' clearance 0.1800 mm; actual 0.0000 mm)
    Rule: netclass 'Default'; error
    @(160.8700 mm, 134.2000 mm): Pad 4 [Net-(U4-Top_Left)] of U4 on F.Cu
    @(168.9719 mm, 125.3413 mm): Polygon [<no net>] of U4 on F.Cu
[clearance]: Clearance violation (netclass 'Default' clearance 0.1800 mm; actual 0.0000 mm)
    Rule: netclass 'Default'; error
    @(160.8700 mm, 134.2000 mm): Pad 4 [Net-(U4-Top_Left)] of U4 on F.Cu
    @(168.9719 mm, 125.3413 mm): Polygon [<no net>] of U4 on F.Cu
[clearance]: Clearance violation (netclass 'Default' clearance 0.1800 mm; actual 0.0000 mm)
    Rule: netclass 'Default'; error
    @(160.8700 mm, 134.2000 mm): Pad 4 [Net-(U4-Top_Left)] of U4 on F.Cu
    @(168.9719 mm, 125.3413 mm): Polygon [<no net>] of U4 on F.Cu
[clearance]: Clearance violation (netclass 'Default' clearance 0.1800 mm; actual 0.0000 mm)
    Rule: netclass 'Default'; error
    @(160.8700 mm, 134.2000 mm): Pad 4 [Net-(U4-Top_Left)] of U4 on F.Cu
    @(168.9719 mm, 125.3413 mm): Polygon [<no net>] of U4 on F.Cu
[clearance]: Clearance violation (netclass 'Default' clearance 0.1800 mm; actual 0.0000 mm)
    Rule: netclass 'Default'; error
    @(173.8700 mm, 125.2000 mm): Pad 5 [Net-(U4-Left)] of U4 on F.Cu
    @(164.2191 mm, 132.9615 mm): Polygon [<no net>] of U4 on F.Cu
[clearance]: Clearance violation (netclass 'Default' clearance 0.1800 mm; actual 0.0000 mm)
    Rule: netclass 'Default'; error
    @(173.8700 mm, 125.2000 mm): Pad 5 [Net-(U4-Left)] of U4 on F.Cu
    @(164.2191 mm, 132.9615 mm): Polygon [<no net>] of U4 on F.Cu
```

AEFeinstein, 2025-09-09:
The only warning I'm iffy on is
> Padstack is not valid (custom pad shape must resolve to a single polygon)

That one's new and may have just been an import problem?

picky33, 2025-09-09:
These are the DRC errors that I was seeing. that's why I was asking if we could use Inkscape or some other program to feather/fillet the ends. there are programs out there that can verify the polygon is sealed (I believe solid works can do this). the error is most likely a line (or 2) that sticks out beyond a point, otherwise it wouldn't render in KiCad.

AEFeinstein, 2025-09-09:
That's fair. If it renders in KiCad and the gerber looks kosher, then we should be fine. Almost makes me want to open a ticket with KiCad to better support this kind of pad, but that's an open source project and I don't want to get uno-reversed.

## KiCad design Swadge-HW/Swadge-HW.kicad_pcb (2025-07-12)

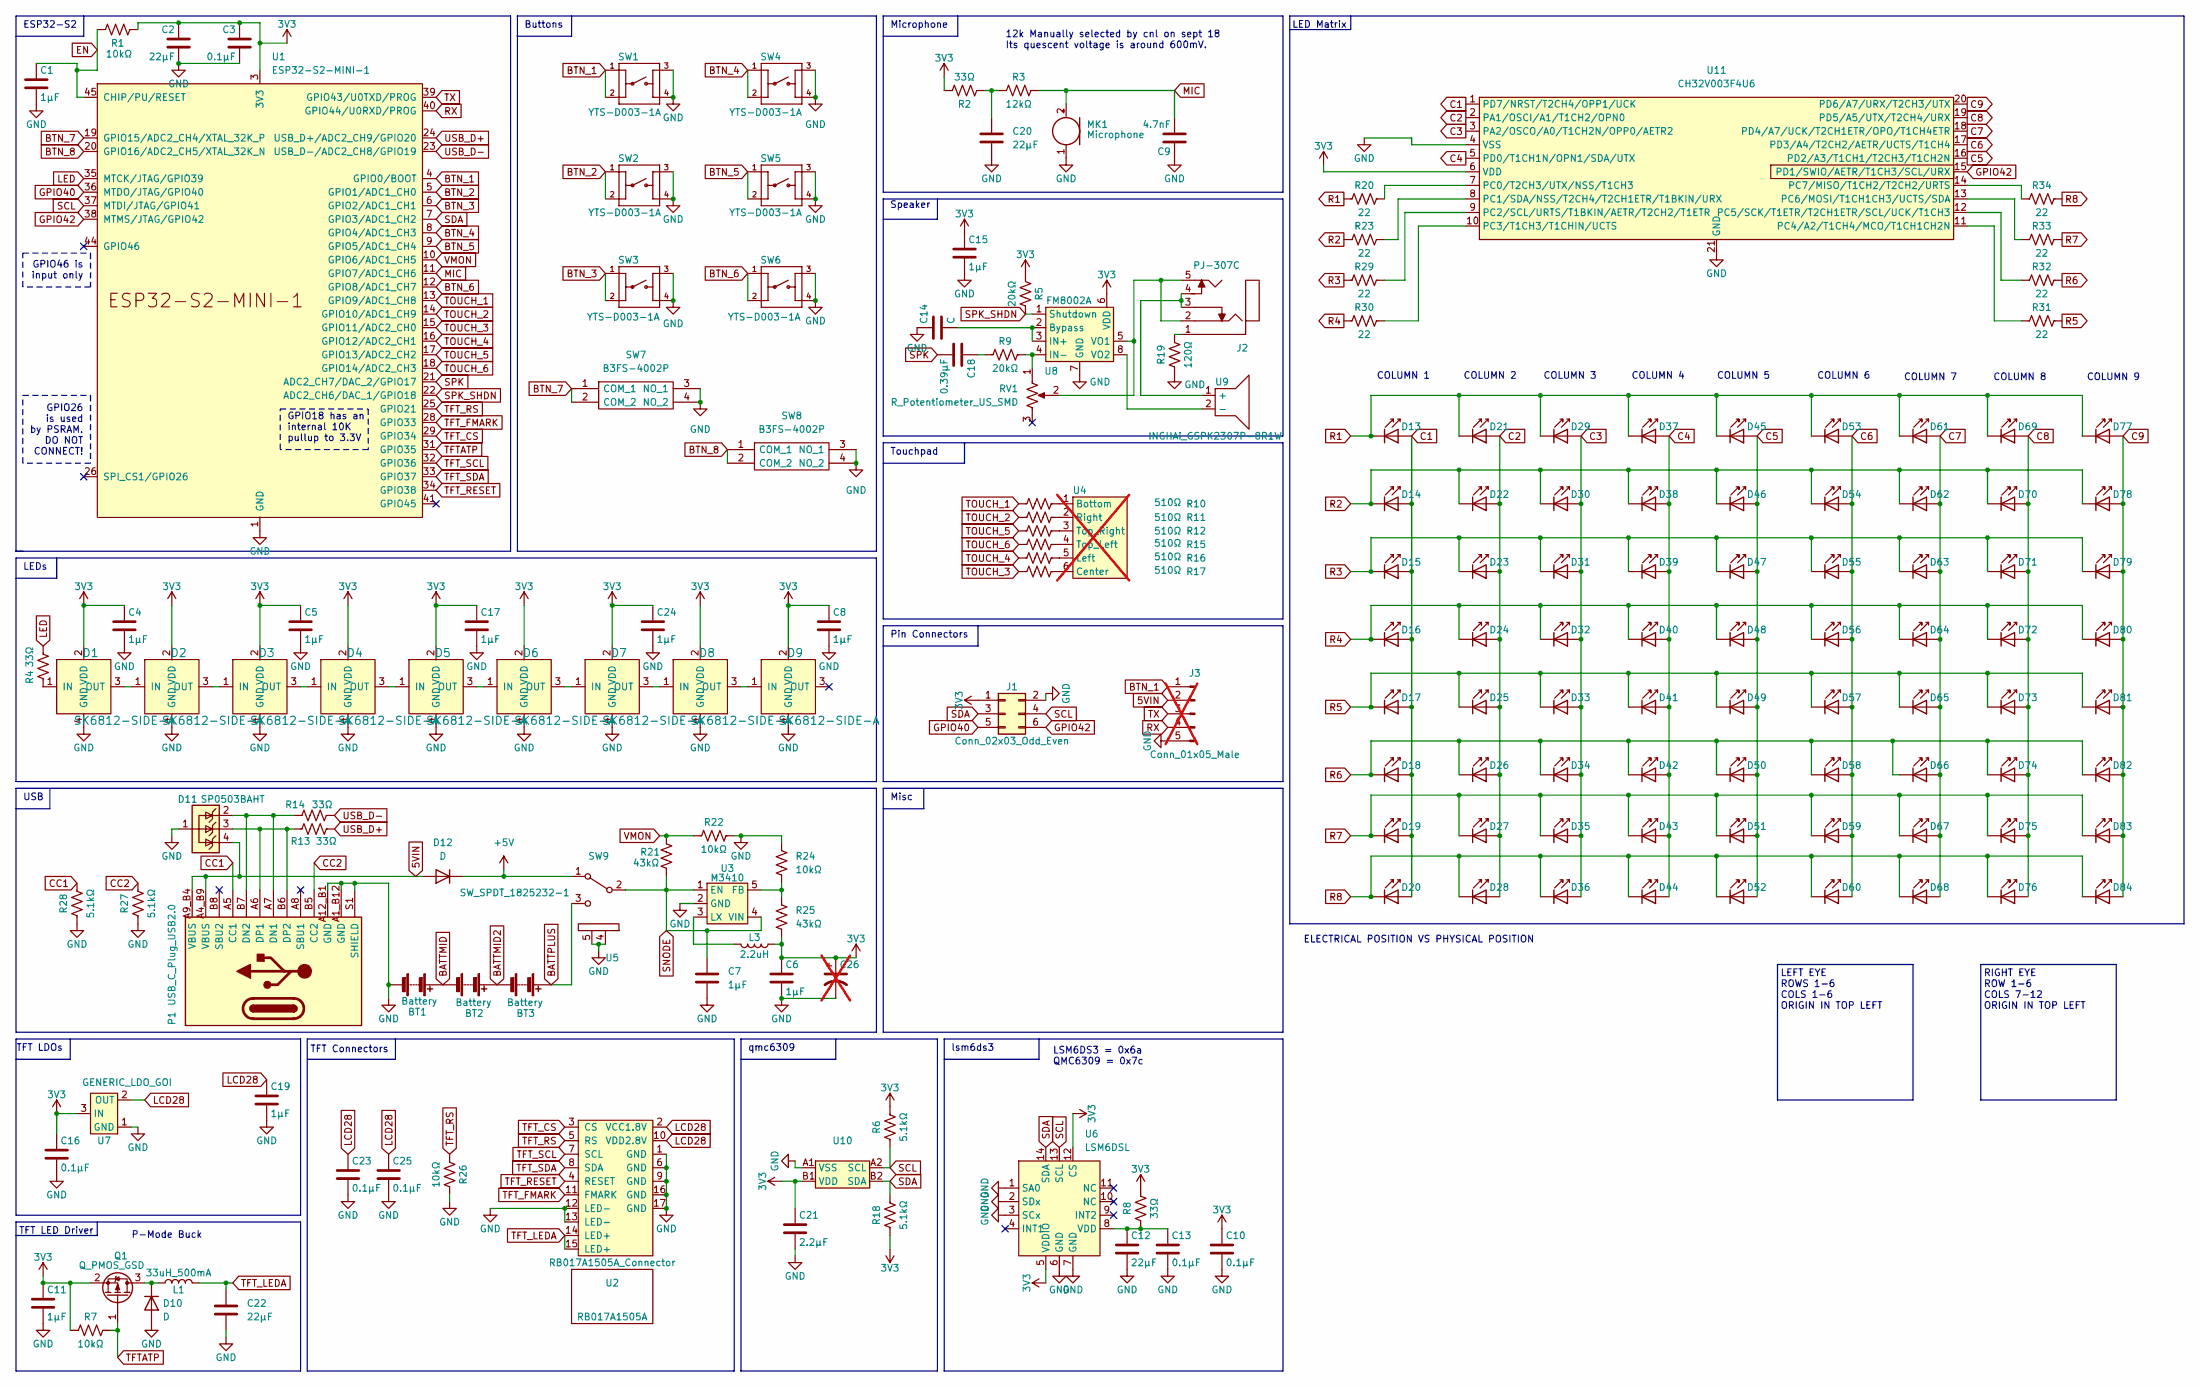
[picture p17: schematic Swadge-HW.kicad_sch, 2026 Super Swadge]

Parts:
BT1, BT2, BT3: Battery; 2460; Digikey 36-2460-ND
C1, C4, C5, C6, C8, C11, C15, C17, C19, C24: 1μF; C_0603_1608Metric; LCSC C15849
C2, C12, C20, C22: 22μF; C_0603_1608Metric; LCSC C159801
C3, C10, C13, C16, C23, C25: 0.1μF; C_0603_1608Metric; LCSC C282519
C7: 1μF; C_0603_1608Metric; LCSC C159801
C9: 4.7nF; C_0603_1608Metric; LCSC C53987
C14: C; C_0603_1608Metric; LCSC C15849
C18: 0.39μF; C_0603_1608Metric; LCSC C376833
C21: 2.2μF; C_0603_1608Metric; LCSC C6119848
C26: C_Polarized_US; C_Radial_D6.3_L5.8_P5.34; LCSC C7465562; not fitted
D1, D2, D3, D4, D5, D6, D7, D8, D9: SK6812-SIDE-A; SK6812_SIDE_2; Digikey 1528-4691-ND
D10, D12: D; D_SMA; Digikey 2616-GS1J-ND
D11: SP0503BAHT; SOT-143; Digikey F2715CT-ND
D13, D14, D15, D16, D17, D18, D19, D20, D21, D22, D23, D24, D25, D26, D27, D28, D29, D30, D31, D32, D33, D34, D35, D36, D37, D38, D39, D40, D41, D42, D43, D44, D45, D46, D47, D48, D49, D50, D51, D52, D53, D54, D55, D56, D57, D58, D59, D60, D61, D62, D63, D64, D65, D66, D67, D68, D69, D70, D71, D72, D73, D74, D75, D76, D77, D78, D79, D80, D81, D82, D83, D84: A-SP192GB1D-A02-4T; LED_0603_1608Metric; LCSC C5355458
J1: Conn_02x03_Odd_Even; PinHeader_2x03_P2.54mm_Vertical; LCSC C92272
J2: PJ-307C; LCSC C16684
J3: Conn_01x05_Male; PinHeader_1x05_P2.54mm_Vertical; LCSC C390683; not fitted
L1: 33uH_500mA; L_0603_1608Metric; LCSC C90317
L3: 2.2uH; L_0603_1608Metric; LCSC C216158
MK1: Microphone; INGHAi_MIC_GMI4013S-2C58DB; LCSC C2835889
P1: USB_C_Plug_USB2.0; USB_C_Receptacle_HRO_TYPE-C-31-M-12; LCSC C2765186
Q1: Q_PMOS_GSD; SOT-23; LCSC C2763847
R1, R7, R22, R24, R26: 10kΩ; R_0603_1608Metric; LCSC C25804
R2, R4, R8, R13, R14: 33Ω; R_0603_1608Metric; LCSC C23140
R3: 12kΩ; R_0603_1608Metric; LCSC C22790
R5, R9: 20kΩ; R_0603_1608Metric; LCSC C2907011
R6, R18, R27, R28: 5.1kΩ; R_0603_1608Metric; LCSC C23186
R10, R11, R12, R15, R16, R17: 510Ω; R_0603_1608Metric; LCSC C2907048
R19: 120Ω; R_0603_1608Metric; LCSC C313655
R20, R23, R29, R30, R31, R32, R33, R34: 22; R_0603_1608Metric; LCSC C2907129
R21, R25: 43kΩ; R_0603_1608Metric; LCSC C23172
RV1: R_Potentiometer_US_SMD; RK10J11R001Y; LCSC C470765
SW1, SW2, SW3, SW4, SW5, SW6: YTS-D003-1A; Digikey 2223-TS04-66-65-BK-100-SMT-ND
SW7, SW8: B3FS-4002P; B3FS4002P; Digikey SW1278CT-ND
SW9: SW_SPDT_1825232-1; 1825232-1; Digikey A107673-ND
U1: ESP32-S2-MINI-1; LCSC C3013908
U2: RB017A1505A; NULL
U3: M3410; SOT-23-5; LCSC C883494
U4: Touch_Teeth_5; not fitted
U5: RB017A1505A_Connector; HCTL HC-FPC-03-10-15RLTAG; Digikey A141392TR-ND
U6: LSM6DSL; LGA-14_3x2.5mm_P0.5mm_LayoutBorder3x4y; LCSC C967633
U7: GENERIC_LDO_GOI; SOT-23; LCSC C347374
U8: FM8002A; SOP-8_3.9x4.9mm_P1.27mm; LCSC C94625
U9: INGHAi_GSPK2307P-8R1W; INGHAi GSPK2308P-8R0.5W; Digikey 102-2500-ND
U10: BGA-4-.83x.83; LCSC C5439871
U11: CH32V003F4U6; QFN-20-1EP_3x3mm_P0.4mm_EP1.65x1.65mm; LCSC C5299908

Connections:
3V3: C2.1, C3.1, C4.1, C5.1, C6.1, C8.1, C10.1, C11.1, C15.1, C16.1, C17.1, C21.1, C24.1, C26.1, D1.2 (VDD), D2.2 (VDD), D3.2 (VDD), D4.2 (VDD), D5.2 (VDD), D6.2 (VDD), D7.2 (VDD), D8.2 (VDD), D9.2 (VDD), J1.1, L3.1, Q1.2 (S), R1.1, R2.2, R5.1, R6.2, R7.1, R8.2, R18.1, R25.2, U1.3 (3V3), U6.5 (VDDIO), U6.12 (CS), U7.3 (IN), U8.6 (VDD), U10.B1 (VDD), U11.6 (VDD)
5VIN: D11.4 (K), D12.2 (A), J3.2, P1.A4_B9 (VBUS), P1.A9_B4 (VBUS)
+5V: D12.1 (K), SW9.1 (A)
BATTMID: BT1.1 (+), BT2.2 (-)
BATTMID2: BT2.1 (+), BT3.2 (-)
BATTPLUS: BT3.1 (+), SW9.3 (C)
BTN_1: J3.1, SW1.1, SW1.2, U1.4 (GPIO0/BOOT)
BTN_2: SW2.1, SW2.2, U1.5 (GPIO1/ADC1_CH0)
BTN_3: SW3.1, SW3.2, U1.6 (GPIO2/ADC1_CH1)
BTN_4: SW4.1, SW4.2, U1.8 (GPIO4/ADC1_CH3)
BTN_5: SW5.1, SW5.2, U1.9 (GPIO5/ADC1_CH4)
BTN_6: SW6.1, SW6.2, U1.12 (GPIO8/ADC1_CH7)
BTN_7: SW7.1 (COM_1), SW7.2 (COM_2), U1.19 (GPIO15/ADC2_CH4/XTAL_32K_P)
BTN_8: SW8.1 (COM_1), SW8.2 (COM_2), U1.20 (GPIO16/ADC2_CH5/XTAL_32K_N)
C1: D13.2 (A), D14.2 (A), D15.2 (A), D16.2 (A), D17.2 (A), D18.2 (A), D19.2 (A), D20.2 (A), U11.1 (PD7/NRST/T2CH4/OPP1/UCK)
C2: D21.2 (A), D22.2 (A), D23.2 (A), D24.2 (A), D25.2 (A), D26.2 (A), D27.2 (A), D28.2 (A), U11.2 (PA1/OSCI/A1/T1CH2/OPN0)
C3: D29.2 (A), D30.2 (A), D31.2 (A), D32.2 (A), D33.2 (A), D34.2 (A), D35.2 (A), D36.2 (A), U11.3 (PA2/OSCO/A0/T1CH2N/OPP0/AETR2)
C4: D37.2 (A), D38.2 (A), D39.2 (A), D40.2 (A), D41.2 (A), D42.2 (A), D43.2 (A), D44.2 (A), U11.5 (PD0/T1CH1N/OPN1/SDA/UTX)
C5: D45.2 (A), D46.2 (A), D47.2 (A), D48.2 (A), D49.2 (A), D50.2 (A), D51.2 (A), D52.2 (A), U11.16 (PD2/A3/T1CH1/T2CH3/T1CH2N)
C6: D53.2 (A), D54.2 (A), D55.2 (A), D56.2 (A), D57.2 (A), D58.2 (A), D59.2 (A), D60.2 (A), U11.17 (PD3/A4/T2CH2/AETR/UCTS/T1CH4)
C7: D61.2 (A), D62.2 (A), D63.2 (A), D64.2 (A), D65.2 (A), D66.2 (A), D67.2 (A), D68.2 (A), U11.18 (PD4/A7/UCK/T2CH1ETR/OPO/T1CH4ETR)
C8: D69.2 (A), D70.2 (A), D71.2 (A), D72.2 (A), D73.2 (A), D74.2 (A), D75.2 (A), D76.2 (A), U11.19 (PD5/A5/UTX/T2CH4/URX)
C9: D77.2 (A), D78.2 (A), D79.2 (A), D80.2 (A), D81.2 (A), D82.2 (A), D83.2 (A), D84.2 (A), U11.20 (PD6/A7/URX/T2CH3/UTX)
CC1: P1.A5 (CC1), R28.2
CC2: P1.B5 (CC2), R27.2
EN: C1.1, R1.2, U1.45 (CHIP/PU/RESET)
GND: BT1.2 (-), C1.2, C2.2, C3.2, C4.2, C5.2, C6.2, C7.2, C8.2, C9.1, C10.2, C11.2, C12.2, C13.2, C14.1, C15.2, C16.2, C17.2, C19.2, C20.2, C21.2, C22.2, C23.2, C24.2, C25.2, C26.2, D1.4 (GND), D2.4 (GND), D3.4 (GND), D4.4 (GND), D5.4 (GND), D6.4 (GND), D7.4 (GND), D8.4 (GND), D9.4 (GND), D10.2 (A), D11.1 (A), J1.2, J3.5, MK1.1 (-), P1.A1_B12 (GND), P1.A12_B1 (GND), P1.S1 (SHIELD), R19.1, R22.2, R24.1, R26.2, R27.1, R28.1, SW1.3, SW1.4, SW2.3, SW2.4, SW3.3, SW3.4, SW4.3, SW4.4, SW5.3, SW5.4, SW6.3, SW6.4, SW7.3 (NO_1), SW7.4 (NO_2), SW8.3 (NO_1), SW8.4 (NO_2), SW9.4 (D), SW9.5 (E), U1.1 (GND), U1.2 (GND), U1.30 (GND), U1.42 (GND), U1.43 (GND), U1.46 (GND), U1.47 (GND), U1.48 (GND), U1.49 (GND), U1.50 (GND), U1.51 (GND), U1.52 (GND), U1.53 (GND), U1.54 (GND), U1.55 (GND), U1.56 (GND), U1.57 (GND), U1.58 (GND), U1.59 (GND), U1.60 (GND), U1.61 (GND), U1.62 (GND), U1.63 (GND), U1.64 (GND), U1.65 (GND), U3.2 (GND), U5.1 (GND), U5.6 (GND), U5.9 (GND), U5.12 (LED-), U5.13 (LED-), U5.16 (GND), U5.17 (GND), U6.1 (SA0), U6.2 (SDx), U6.3 (SCx), U6.6 (GND), U6.7 (GND), U7.1 (GND), U8.7 (GND), U10.A1 (VSS), U11.4 (VSS), U11.21 (GND)
GPIO40: J1.5, U1.36 (MTDO/JTAG/GPIO40)
GPIO42: J1.6, U1.38 (MTMS/JTAG/GPIO42), U11.15 (PD1/SWIO/AETR/T1CH3/SCL/URX)
LCD28: C19.1, C23.1, C25.1, U5.2 (VCC1.8V), U5.10 (VDD2.8V), U7.2 (OUT)
LED: R4.2, U1.35 (MTCK/JTAG/GPIO39)
MIC: C9.2, MK1.2 (+), R3.2, U1.11 (GPIO7/ADC1_CH6)
unnamed: C18.1, R9.1
unnamed: C20.1, R2.1, R3.1
unnamed: D1.1 (IN), R4.1
unnamed: D1.3 (OUT), D2.1 (IN)
unnamed: D2.3 (OUT), D3.1 (IN)
unnamed: D3.3 (OUT), D4.1 (IN)
unnamed: D4.3 (OUT), D5.1 (IN)
unnamed: D5.3 (OUT), D6.1 (IN)
unnamed: D6.3 (OUT), D7.1 (IN)
unnamed: D7.3 (OUT), D8.1 (IN)
unnamed: D8.3 (OUT), D9.1 (IN)
unnamed: D10.1 (K), L1.1, Q1.3 (D)
unnamed: J2.1, R19.2
unnamed: D11.2 (K), P1.A7 (DN1), P1.B7 (DN2), R14.2
unnamed: D11.3 (K), P1.A6 (DP1), P1.B6 (DP2), R13.2
unnamed: R24.2, R25.1, U3.5 (FB)
unnamed: L3.2, U3.3 (LX)
unnamed: R10.2, U4.1 (Bottom)
unnamed: R17.2, U4.6 (Center)
unnamed: R16.2, U4.5 (Left)
unnamed: R11.2, U4.2 (Right)
unnamed: R15.2, U4.4 (Top_Left)
unnamed: R12.2, U4.3 (Top_Right)
unnamed: C12.1, C13.1, R8.1, U6.8 (VDD)
unnamed: C14.2, U8.2 (Bypass), U8.3 (IN+)
unnamed: R9.2, RV1.1, U8.4 (IN-)
unnamed: J2.2, J2.5, RV1.2, U8.5 (VO1)
unnamed: U8.8 (VO2), U9.2 (-)
unnamed: J2.3, J2.4, U9.1 (+)
unnamed: R20.2, U11.7 (PC0/T2CH3/UTX/NSS/T1CH3)
unnamed: R23.2, U11.8 (PC1/SDA/NSS/T2CH4/T2CH1ETR/T1BKIN/URX)
unnamed: R29.2, U11.9 (PC2/SCL/URTS/T1BKIN/AETR/T2CH2/T1ETR)
unnamed: R30.2, U11.10 (PC3/T1CH3/T1CHIN/UCTS)
unnamed: R31.1, U11.11 (PC4/A2/T1CH4/MCO/T1CH1CH2N)
unnamed: R32.1, U11.12 (PC5/SCK/T1ETR/T2CH1ETR/SCL/UCK/T1CH3)
unnamed: R33.1, U11.13 (PC6/MOSI/T1CH1CH3/UCTS/SDA)
unnamed: R34.1, U11.14 (PC7/MISO/T1CH2/T2CH2/URTS)
R1: D13.1 (K), D21.1 (K), D29.1 (K), D37.1 (K), D45.1 (K), D53.1 (K), D61.1 (K), D69.1 (K), D77.1 (K), R20.1
R2: D14.1 (K), D22.1 (K), D30.1 (K), D38.1 (K), D46.1 (K), D54.1 (K), D62.1 (K), D70.1 (K), D78.1 (K), R23.1
R3: D15.1 (K), D23.1 (K), D31.1 (K), D39.1 (K), D47.1 (K), D55.1 (K), D63.1 (K), D71.1 (K), D79.1 (K), R29.1
R4: D16.1 (K), D24.1 (K), D32.1 (K), D40.1 (K), D48.1 (K), D56.1 (K), D64.1 (K), D72.1 (K), D80.1 (K), R30.1
R5: D17.1 (K), D25.1 (K), D33.1 (K), D41.1 (K), D49.1 (K), D57.1 (K), D65.1 (K), D73.1 (K), D81.1 (K), R31.2
R6: D18.1 (K), D26.1 (K), D34.1 (K), D42.1 (K), D50.1 (K), D58.1 (K), D66.1 (K), D74.1 (K), D82.1 (K), R32.2
R7: D19.1 (K), D27.1 (K), D35.1 (K), D43.1 (K), D51.1 (K), D59.1 (K), D67.1 (K), D75.1 (K), D83.1 (K), R33.2
R8: D20.1 (K), D28.1 (K), D36.1 (K), D44.1 (K), D52.1 (K), D60.1 (K), D68.1 (K), D76.1 (K), D84.1 (K), R34.2
RX: J3.4, U1.40 (GPIO44/U0RXD/PROG)
SCL: J1.4, R6.1, U1.37 (MTDI/JTAG/GPIO41), U6.13 (SCL), U10.A2 (SCL)
SDA: J1.3, R18.2, U1.7 (GPIO3/ADC1_CH2), U6.14 (SDA), U10.B2 (SDA)
SNODE: C7.1, R21.2, SW9.2 (B), U3.1 (EN), U3.4 (VIN)
SPK: C18.2, U1.21 (ADC2_CH7/DAC_2/GPIO17)
SPK_SHDN: R5.2, U1.22 (ADC2_CH6/DAC_1/GPIO18), U8.1 (Shutdown)
TFTATP: Q1.1 (G), R7.2, U1.31 (GPIO35)
TFT_CS: U1.29 (GPIO34), U5.3 (CS)
TFT_FMARK: U1.28 (GPIO33), U5.11 (FMARK)
TFT_LEDA: C22.1, L1.2, U5.14 (LED+), U5.15 (LED+)
TFT_RESET: U1.34 (GPIO38), U5.4 (RESET)
TFT_RS: R26.1, U1.25 (GPIO21), U5.5 (RS)
TFT_SCL: U1.32 (GPIO36), U5.7 (SCL)
TFT_SDA: U1.33 (GPIO37), U5.8 (SDA)
TOUCH_1: R10.1, U1.13 (GPIO9/ADC1_CH8)
TOUCH_2: R11.1, U1.14 (GPIO10/ADC1_CH9)
TOUCH_3: R17.1, U1.15 (GPIO11/ADC2_CH0)
TOUCH_4: R16.1, U1.16 (GPIO12/ADC2_CH1)
TOUCH_5: R12.1, U1.17 (GPIO13/ADC2_CH2)
TOUCH_6: R15.1, U1.18 (GPIO14/ADC2_CH3)
TX: J3.3, U1.39 (GPIO43/U0TXD/PROG)
USB_D+: R13.1, U1.24 (USB_D+/ADC2_CH9/GPIO20)
USB_D-: R14.1, U1.23 (USB_D-/ADC2_CH8/GPIO19)
VMON: R21.1, R22.1, U1.10 (GPIO6/ADC1_CH5)

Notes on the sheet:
LED Matrix
Pin Connectors
GPIO46 is input only
COLUMN 7
TFT LDOs
P-Mode Buck
Touchpad
COLUMN 9
ELECTRICAL POSITION VS PHYSICAL POSITION
lsm6ds3
Speaker
LEFT EYE ROWS 1-6 COLS 1-6 ORIGIN IN TOP LEFT
COLUMN 3
LSM6DS3 = 0x6a QMC6309 = 0x7c
12k Manually selected by cnl on sept 18 Its quescent voltage is around 600mV.
Buttons
GPIO26 is used by PSRAM. DO NOT CONNECT!
qmc6309
ESP32-S2
GPIO18 has an internal 10K pullup to 3.3V
Microphone
LEDs
COLUMN 4
Misc
COLUMN 1
COLUMN 2
COLUMN 5
TFT LED Driver
COLUMN 8
COLUMN 6
TFT Connectors
RIGHT EYE ROW 1-6 COLS 7-12 ORIGIN IN TOP LEFT
USB

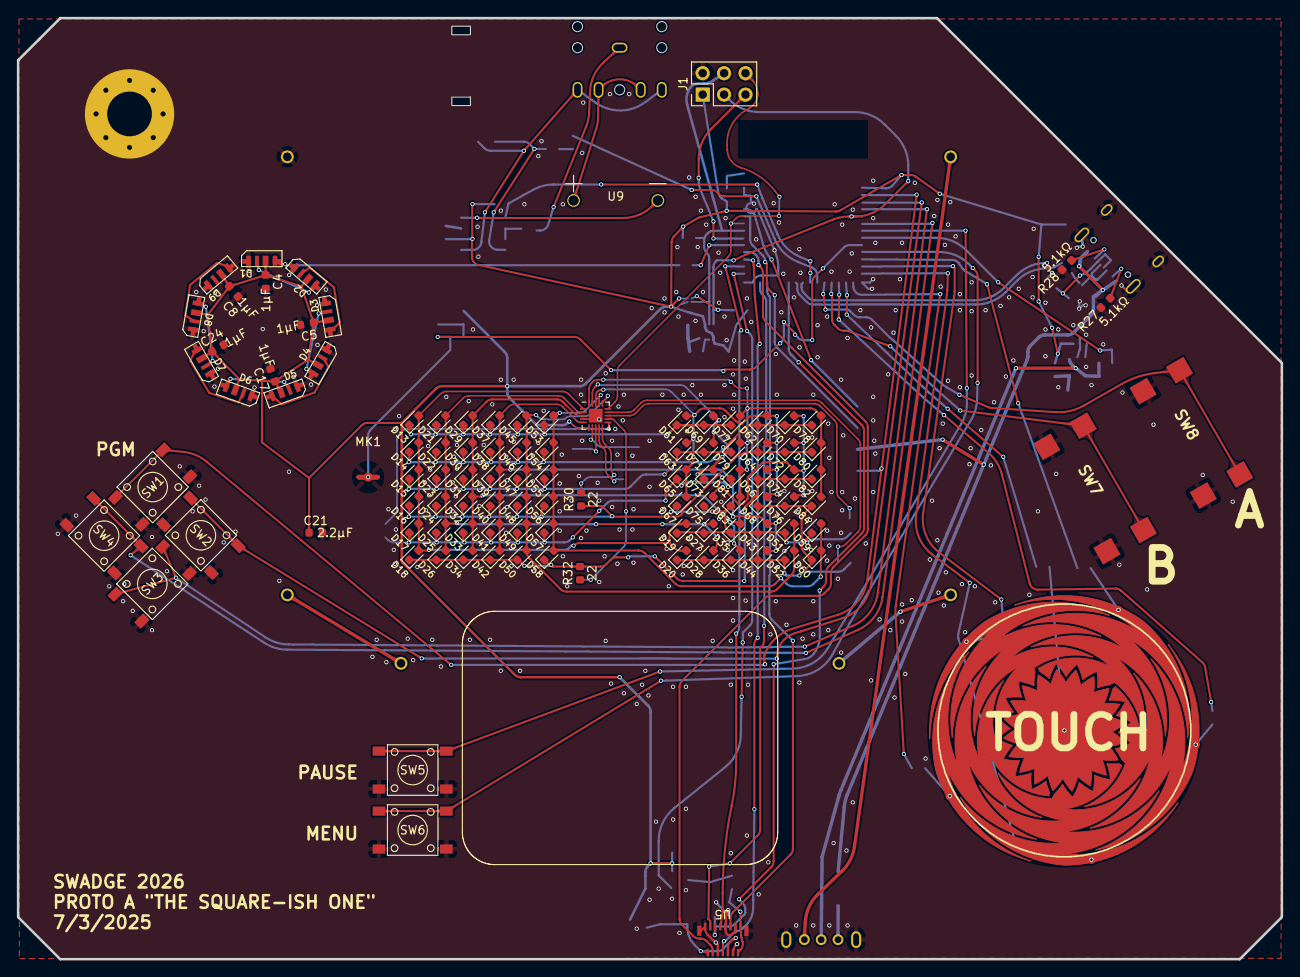
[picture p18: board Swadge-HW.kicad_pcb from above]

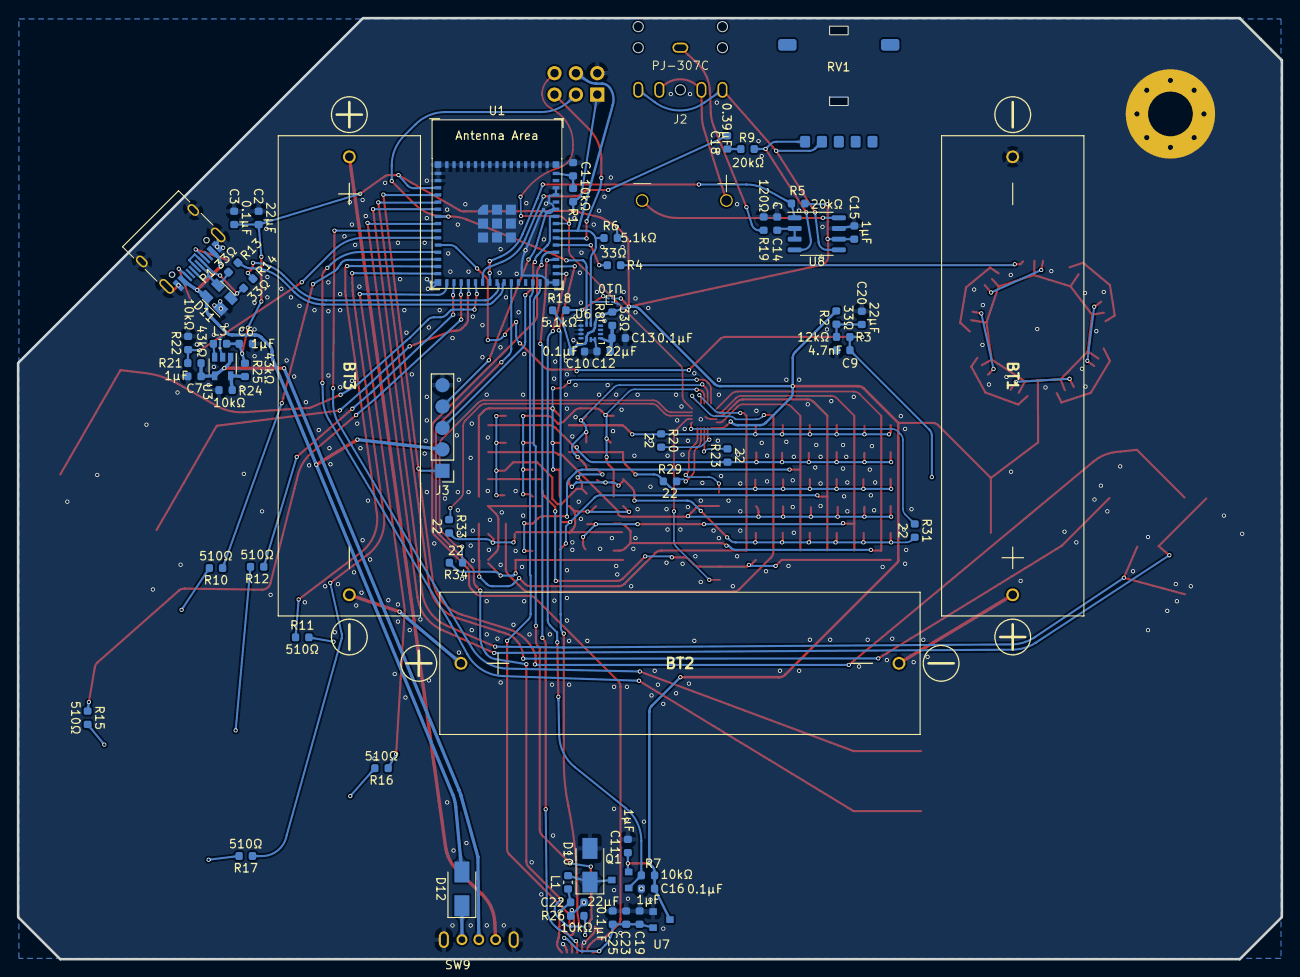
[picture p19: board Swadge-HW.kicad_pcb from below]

Board: 2 copper layers, 150.0 x 111.7 mm, 175 parts (69 on the bottom side), 101 nets.

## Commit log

2024-07-21 Replace buzzer with speaker Clean up schematic
    [Swadge-HW.kicad_sch]
2024-07-21 Add LCSC part numbers, costs
    [Swadge-HW.kicad_sch]
2024-07-21 Reset PCB
    [Swadge-HW.kicad_pcb]
2024-07-21 #1 Add ESD resistors to touchpads
    [Swadge-HW.kicad_pcb, Swadge-HW.kicad_sch]
2024-07-21 Added volume potentiometer
    [Swadge-HW.kicad_pcb, Swadge-HW.kicad_sch]
2024-07-22 Put touchpad on board
    [Swadge-HW.kicad_pcb, Swadge-HW.kicad_sch]
2024-07-23 Add idea of a shape and layout
    [Swadge-HW.kicad_pcb]
2024-07-30 Added acrylic sausage, SMD pot
    [Swadge-HW.kicad_pcb, Swadge-HW.kicad_sch, sausage.step]
2024-08-09 Updated to new board shape
    [Swadge-HW.kicad_pcb, Swadge-HW.kicad_sch]
2024-08-10 Placed big parts
    [Swadge-HW.kicad_pcb]
2024-08-10 Added condiment part
    [Swadge-HW.kicad_pcb, Swadge-HW.kicad_sch, condiment.step]
2024-08-14 Layout v0.5
    Placement of 80% of SMD components
    Add QMC6309
    DNP D9
    Move Power Switch to right dog
    Bump Aux port over
    [Swadge-HW.kicad_pcb, Swadge-HW.kicad_sch]
2024-08-15 Layout 0.6
    still tweaking
    [Swadge-HW.kicad_pcb]
2024-08-16 Layout 0.7
    Is endless screaming an option for a description?
    10lbs of swadge in a 5lb layout. Moved some USB peripherals after plagiarizing from the gunship layout, more attempts to work myself out of the corner of my own creation. Need to consider moving all 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
    [Swadge-HW.kicad_pcb]
2024-08-19 Layout 0.9
    for review
    [Swadge-HW.kicad_pcb]
2024-08-20 Fix DRC things
    [Swadge-HW.kicad_pcb]
2024-08-29 update from changes made by charlesl pre-order
    [Swadge-HW.kicad_pcb, Swadge-HW.kicad_sch]
2024-09-02 Update to order for rev - before checking footprint on ESP32-S2
    [Swadge-HW.kicad_pcb, Swadge-HW.kicad_sch]
2024-09-02 After updating footprint
    [Swadge-HW.kicad_pcb]
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2024-09-18 Increase board size and add new acrylic
    grew pcb, added bun outline, nudged some components
    [Swadge-HW.kicad_pcb, condiment.step, pcb-outline.dxf]
2024-09-19 Modify silk art and minor layout adjustments
    Bump screen to right, bump switch inside, update silk art, nudge LED for clearance concerns
    [Swadge-HW.kicad_pcb, Swadge-HW.kicad_sch, condiment.dxf]
2024-09-23 Update silkscreen
    [Swadge-HW.kicad_pcb]
2024-09-23 Add PGM to silkscreen
    [Swadge-HW.kicad_pcb]
2024-09-23 Route USB & power switch circuitry
    [Swadge-HW.kicad_pcb]
2024-09-24 Lots of routing
    [Swadge-HW.kicad_pcb]
2024-09-24 Fully route
    [Swadge-HW.kicad_pcb]
2024-09-26 Cleanup routing
    [Swadge-HW.kicad_pcb]
2024-09-26 Fix PGM silkscreen
    [Swadge-HW.kicad_pcb]
2024-09-26 Added teardrops
    [Swadge-HW.kicad_pcb]
2024-09-26 More filleting, promise I'm done smoothing things
    [Swadge-HW.kicad_pcb]
2024-09-30 Pull passives back from edge
    [Swadge-HW.kicad_pcb]
2024-10-01 Emerald touchpad, adjust characters
    [Swadge-HW.kicad_pcb]
2024-10-03 Add electrolytic capacitor C26
    add capacitor for noise management
    [Swadge-HW.kicad_pcb, Swadge-HW.kicad_sch]
2024-10-07 Generate RB manufacturing data, small edits
    Change footprint for C26 + BOM Data
    Add notch in Acrylic for fitment
    Update schematic to reflect C26 change
    Add quote data
    Update condiment dxf/svg
    [Hot Dog Quotation.xlsx, Swadge-HW.kicad_sch, Template-for-PCBA-Quotation.xlsx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]
2024-10-07 Update mfg files
    Updated mfg files for elecrow quote
    [Hot Dog Quotation.xlsx, Swadge-HW.kicad_sch]
2024-10-09 Mostly art and silk updates
    add garbotnik
    edit silk
    add touchpad label
    update condiment step
    [Hot Dog Quotation.xlsx, condiment.step]
2024-10-10 quoting data to prepare for order
    [Hot Dog Quotation.xlsx]
2024-10-10 fix short on garbotnik, schematic parity
    C26 pointed at different part on schematic
    garbotnik was shorted to ground
    [Swadge-HW.kicad_sch]
2024-10-11 Rev 0 for release
    [Hot Dog Quotation.xlsx]
2024-10-14 final_updated_final_no_this_one
    DNP U10, C21
    Fixing my dyslexia in the quote information
    [Hot Dog Quotation.xlsx, Swadge-HW.kicad_sch]
2024-10-21 Rev 1.1
    add R19
    [Hot Dog Quotation.xlsx, Swadge-HW.kicad_sch]
2024-11-21 Silk rev D
    Add screen outline
    [Swadge-HW-F_Silkscreen.gbr]
2025-02-02 Paperwork makes the dream work
    Schematic, render, readme updates
    [Swadge-HW.kicad_sch]
2025-02-02 3D files
    [2025-swadge-d-pad.3mf, 2025-swadge-d-pad.stl, Shelldog-3dp.3mf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]
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2025-03-29 Clean out last year's files (PCB, Art, Shell) Update READMEs
    [2025-swadge-d-pad.3mf, 2025-swadge-d-pad.stl, Hot Dog Quotation.xlsx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]
2025-06-08 Add LED matrix and CH32v003 Repopulate magnometer and associated components DNP giant capacitor Change sheet size to 11x17 Change labels to 2026
    [Swadge-HW.kicad_sch]
2025-06-25 preliminary layout
    placed most of the important bits
    [Swadge-HW.kicad_pcb, Swadge-HW.kicad_sch]
2025-06-26 Half the routing done
    Do you think God stays in heaven because he, too, lives in fear of what he's created here on earth?
    [Swadge-HW.kicad_pcb, Swadge-HW.kicad_sch]
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2025-07-09 fixing some routing problems
    haven't resolved DRC just yet. someday i will learn how github works
    [Swadge-HW.kicad_pcb]
2025-07-11 Rearrange LEDs, buttons. Fix DRC
    [Swadge-HW.kicad_pcb]
2025-07-11 Fixed DRC errors and Added Thermal Reliefs
    Added some thermal relief to parts. Fixed Some DRC errors.
    Now there are 0 DRC errors.
    [Swadge-HW.kicad_pcb]
2025-07-11 Added A Relief Hole
    Like the title says. i added a "relief" hole, mainly to allow people to hang it up via a Lanyard or something
    [Swadge-HW.kicad_pcb]
2025-07-15 Create rev A shape, routing
    Replaced screen footprint with variant that tucks ribbon
    scale touchpad to 80%
    add R35 5.1k pullup on GPIO42 for CH32v003
    DNP D7-D9 + caps
    [Swadge-HW.kicad_sch]
2025-07-18 corrected a bunch of DRC errors, did some of the work that was suggested on Slack and improved the fill by manipulating some of the tracks and Via’s.
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2025-07-18 Added missing part to lib, fixed DRC warnings, updated submodule
    [Swadge-HW.kicad_sch]
2025-08-26 Fixing footprint errors on Ls and SAO
    Associated with
    https://github.com/AEFeinstein/Super-2026-Swadge-HW/issues/9
    [Swadge-HW.kicad_sch]
2025-08-28 What am I even doing
    [Swadge-HW.kicad_pcb]
2025-08-28 Oops wrong branch
    [Swadge-HW.kicad_pcb]
2025-09-03 BOM adjustments and unrouting for rev B
    fixing problems from issues #7 #8 #9 #10
    [Swadge-HW.kicad_sch]
2025-09-03 Fixing LED array pinout
    adjusting pinout to ch32v003 to match the SAO pinout. flipped LEDs 180deg in schematic. please check my work I am so nervous about this
    [Swadge-HW.kicad_sch]
2025-09-03 reroute rev B
    Rerouted with updates to sch and footprints
    [Swadge-HW.kicad_sch]
2025-09-04 BOM adjustments for production
    [Swadge-HW.kicad_sch, Swadge-HW.xlsx]
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2025-09-05 Fixed the screen 3D Model, now its centered on the footprint and the cable wraps around and connects to the bottom.
2025-09-06 Fix button order
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2025-09-08 Dismantled a couple minor DRC errors and Wacked a few Warnings. Tee’d up some Thermal relief via’s to a few of the pins (overkill honestly).
2025-09-09 Silkscreen integration and cleanup
    SAO part fix, pin variant was selected not header
    integrate greg's silkscreen design
    cleanup refdes all over the board
    add version, circuitboards, website on back
    touchpad is still yelling about polygons but at this point i don't really care
    [acrylic_992025.dxf]
2025-09-10 Show correct LED models
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2025-09-17 bump to v1.1
    replace RV1 with available component
    [Swadge-HW.kicad_sch]
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2025-11-20 Update Swadge-HW.kicad_pcb
    outline fix for v1.2
2025-12-23 Uploaded Swadge Add-on STEP files
    Added Shell Prototype file, Diffuser addon plus template design, as well as alternate Printable diffuser crest.
    [Corruption Crest.step, Crest-Diffuser-Template.step, M-Diffuser.step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]
2026-01-19 Added Orcaslicer compatible 3MF files
    [Corruption-Crest+Acrylic-Orca.3mf, Fancy-M-Diffuser.3mf, Open-Visor-orca-MK4.3mf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]
2026-04-04 Revert "initial commit"
    This reverts commit 0464ea491c95b659d104dd14c666d512c40c896c.
    [Corruption Crest.step, Corruption-Crest+Acrylic-Orca.3mf, Crest-Diffuser-Template.step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]
